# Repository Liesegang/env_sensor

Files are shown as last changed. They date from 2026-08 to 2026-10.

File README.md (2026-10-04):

# Environment sensors

機種ごとに回路・ファームウェア・受信アプリ・プロトコルをまとめる。

```text
card/
  hardware/       KiCad / Fusionの回路・基板・3Dモデル
  firmware/       実装用ディレクトリ
outdoor/
  hardware/       env_sensor_3の回路・基板
  firmware/       nRF54L15 / Zephyr、driver/に各センサー
  software/       TypeScript / ReactのWeb BLE受信アプリ
  protocol/       BLEの共通スキーマ・Cコード生成
room/
  hardware/       env_sensor_1aの回路・基板
docs/
  datasheets/     機種共通のメーカー資料
```

Outdoorの開発・検証は[ファームウェア](outdoor/firmware/README.md)、
[Web受信アプリ](outdoor/software/README.md)、[BLE仕様](outdoor/protocol/README.md)を参照。
資料の一覧は[データシート](docs/datasheets/README.md)にある。

BMV080のIC9はセンサーpinとコネクターpadの対応が反転している。
[配線の照合結果](outdoor/hardware/BMV080-pin-review.md)を参照。回路・基板の配線は未修正。

リポジトリのルートから実行する：

```sh
python3 outdoor/protocol/generate.py --check
outdoor/firmware/scripts/fw test
cd outdoor/software
npm ci
npm run dev
```

ファームウェアのSDK、バックアップ、実機ログは`outdoor/firmware/.local/`へ保存し、Gitに含めない。

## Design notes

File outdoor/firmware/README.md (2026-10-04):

# Outdoor 基板のファームウェア

`outdoor/hardware/env_sensor_3.fsch` / `.fbrd`用のnRF Connect SDK / Zephyrアプリ。
ディレクトリは`outdoor/firmware`。回路・受信アプリ・プロトコルも`outdoor/`配下に置く。
起動時にブザーを停止し、I2Cを1回スキャンした後、各測定値を1秒ごとに`printk()`する。
ブザー試験は無効。BLEは同じ測定値を1秒ごとにNotifyする。

## 実装型番と接続

回路の`parts/part`の`PARTS`属性とユーザーの指定を優先する。
流用されたパッド、記号、ライブラリの名前から実装型番を決めない。

| 部品 | 型番の根拠 | センサー | 接続 |
| --- | --- | --- | --- |
| IC3 | ユーザーが実装型番を確認 | SFA40 | MCU側I2C `0x5d`、実機検証済み |
| IC4 | 実機device ID=`0x0121` | OPT4001 | MCU側I2C `0x45` |
| IC5 | `PARTS=bme690` | BME690 | MCU側I2C `0x76` |
| IC6 | `PARTS=spg41`（回路の表記） | SGP41 | MCU側I2C `0x59` |
| IC7 | `PARTS=SHT4x-Axx`、ユーザー指定はSHT45 | SHT45 | STCC4の補助I2C |
| IC8 | partsの`value=STCC4-D-R3`、product IDを取得済み | STCC4 | MCU側I2C `0x64` |
| IC9 | partsの`value=BMV080`、ユーザーが型番を確認 | BMV080 | MCU側I2C `0x54`、未接続・配線修正が必要 |
| IC10 | partsの`deviceset=AS3935`を暫定採用、`PARTS`未指定 | AS3935 | MCU側I2C `0x03`は仮設定、未接続 |

TWIM30、SCL=P0.03、SDA=P0.04、100kHzを使う。
R5/R6は5.1kΩの外部プルアップ。PCA9515のENは3.3Vにつながり、
下流のSCL1/SDA1へ接続される。
SHT45はSTCC4の専用SCL_C/SDA_Cにつながるため、STCC4が取得した温湿度を利用する。

スキャンは起動後1秒待ち、7bitアドレス`0x01..0x03`と`0x08..0x77`を
データ長0のWriteとSTOPで調べる。スキャンでは測定コマンドを送らない。
NACKは未検出、タイムアウト等は異常として表示し中断する。
起動時のバス復旧に失敗した場合はSCL/SDAの状態を表示する。

## ドライバーと取得値

すべてのモジュールを`driver/`へ置く。各`include/`が公開API。
通常のAPIは成功時0、失敗時に負のerrnoを返す。初期化失敗はセンサーごとに表示し、
ほかのセンサーの取得を続ける。読み取り失敗時には古い値を表示しない。

| モジュール | 取得・表示する値 |
| --- | --- |
| `opt4001` | 照度lux、mantissa、exponent、counter、device ID |
| `bme690` | 温度°C、湿度%RH、気圧Pa、ガス抵抗Ω、gas valid、heater stable、status、測定index、gas index、heater設定、chip ID、variant ID |
| `sgp41` | VOC Index、NOx Indexと各有効フラグ、raw VOC・NOx、NOx raw有効フラグ、conditioning、補償入力と出所、self-test結果、serial |
| `stcc4` | CO₂ ppm、status、product ID、serial、SHT45のraw温湿度 |
| `sht45` | STCC4経由のraw値を温度°C・湿度%RHへ変換 |
| `bmv080` | PM1.0・PM2.5・PM10の質量濃度と粒子数濃度、遮蔽・範囲外フラグ、経過時間。SDK v11.2.0でビルド確認済み、通常構成は無効 |
| `as3935` | 雷・過大ノイズ・妨害信号のイベント、エネルギー、推定距離・頭上・範囲外、検出設定、RC校正状態。現在は無効 |
| `sfa40` | HCHO ppb、温度°C、湿度%RH、raw値、暖機状態、product ID、serial。通常構成で有効 |
| `buzzer` | `buzzer_init()`、`buzzer_start()`、`buzzer_stop()`によるPWM制御 |
| `common` | SensirionのCRC8・I2Cコマンド、SGP41補償値、OPT4001のデコード |

各周期は`SAMPLE <連番> at <経過ms> ms`から始まる。
変換待ち時間を含めて開始時刻を1秒間隔に保ち、周期を超えた場合は
期限を過ぎた分をスキップして`SAMPLE OVERRUN`を表示する。
温度・湿度は内部ではm°C・0.001%RHとして保持し、整数で小数表示する。

SGP41は最初の10秒間をconditioningとし、その間は`raw_nox=0 nox_valid=0`。
その後VOCとNOxの両方を取得する。補償には同じ周期のSHT45温湿度を優先し、
取得失敗時はBME690、両方失敗時は25°C・50%RHを使う。
Sensirion公式Gas Index Algorithm v3.2.0でVOC Index・NOx Index（1〜500）へ変換する。
最初の約45秒はアルゴリズムの暖機中として有効フラグをfalseにし、Webでは`—`を表示する。
NOxはconditioning後から暖機を始める。欠測時は履歴をリセットする。
raw値は詳細表示・CSV用に保持する。[SGP41の変換と検証](driver/sgp41/README.md)を参照。

STCC4の測定周期は内部クロックの許容差により1000ms ±150ms。
データ未準備のNACK時はコマンドを再送せず、150ms後に1回だけ再読する。
再読でも未準備なら`-EAGAIN`として欠測を通知し、以前の値は再利用しない。

BME690はBosch公式SensorAPI v1.1.0を`driver/bme690/vendor/`に同梱し、
校正データから温湿度・気圧・ガス抵抗を計算する。forced mode、heater 300°C / 100ms。
BSECによるIAQ等は未実装。OPT4001はDTS品の係数437.5µlux/countで変換する。

## 後で接続するセンサー

SFA40は接続を確認し初期設定で有効。BMV080・AS3935は初期設定で無効。無効なモジュールの初期化・読み取りは呼ばない。
接続後、`prj.conf`で必要なものだけ有効にし、ビルド・書き込みする。

```ini
CONFIG_APP_AS3935=y
CONFIG_APP_SFA40=y
```

AS3935のアドレスは`0x03`を仮設定している。実際のモジュールのA0/A1に合わせ、
Devicetreeの`reg`を`0x01`・`0x02`・`0x03`のいずれかへ変更する。
現在の回路にはIRQ接続がないため1秒ごとにポーリングし、周期内の複数イベントは
個別に取得できない。新しい雷かどうかは`lightning`で判定する。
[AS3935の設定とAPI](driver/as3935/README.md)を参照。

SFA40は電源投入後の最初の1分に`ready=0`、最初の10分に`within_spec=0`を表示する。
HCHO濃度と合わせて暖機状態を確認する。[SFA40の設定とAPI](driver/sfa40/README.md)を参照。

ユーザー提供のBMV080 SDK v11.2.0を`.local/`へ導入し、
Cortex-M33のsoft-floatライブラリでARMビルドとリンクを確認した。
実機のPM測定は未検証。基板IC9のpin/pad対応は反転しているため、
[配線の照合結果](../hardware/BMV080-pin-review.md)を確認し、接続を修正してから使用する。
コードだけを検証するコマンド（書き込みはしない）：

```sh
./scripts/fw test-bmv080 ~/Downloads/bmv080-sdk-v11-2-0.zip
```
[BMV080の導入手順](driver/bmv080/README.md)を参照。

## 環境と検証

macOSのnRF Connect SDK **v3.4.1**と対応ツールチェーンを使用する。
SDKの標準パスは`/opt/nordic/ncs/v3.4.1`。別の場所では`NCS_DIR`で指定する。
`nrfutil`の`sdk-manager` / `device`とSEGGER J-Linkが必要。

以下は`outdoor/firmware`で実行する。

```sh
nrfutil install sdk-manager
nrfutil install device
./scripts/fw setup
./scripts/fw doctor
./scripts/fw build
./scripts/fw test
```

`test`はビルド後に回路図・PCB・Devicetreeの接続、PARTS指定、PWM極性、
I2Cポート、クロック、DC/DC、RTT、ARM成果物、BLE設定と追加モジュールの有効・無効を11件で検証する。
さらに実際のCコードをホストでコンパイルし、CRC正常値・全1bit破損、
照度・温湿度の単位と境界、SGP41補償を9件で確認する。
追加したAS3935・SFA40の実際のCソースを模擬I2Cで実行し、初期化・CRC・状態・
単位変換・距離コード・IRQ解除・校正・未接続時のエラーを11件で確認する。
STCC4の正常読出し・NACK再読・再読上限・コマンド失敗・CRC破損・タイムアウトを6件で確認する。合計37件。
さらにBLEのCエンコーダーの容量境界・分割を検証し、Webの互換テスト用データを生成する。
通常構成のBMV080は無効側だけがビルド対象。
Gas Indexのconditioning・暖機・基準値・信号変化・欠測・無効入力を実際の公式Cコードで追加検証する。
BMV080のSDK有効側は`test-bmv080`で別途ビルド・11件の構成検証を行う。
成果物は`build/zephyr/zephyr.{elf,hex,bin}`。
センサーAPIには変換待ち時間があるため、割り込みハンドラーから呼ばない。

## 書き込みとリアルタイムログ

CON1は1=nRESET、2=3.3V/VTref、3=SWDIO、4=GND、5=SWCLK。
基板を給電してJ-Linkを接続する。確認したシリアル番号は`69730357`。

```sh
./scripts/fw flash 69730357
```

テスト成功後、既存アプリ領域を`.local/before_flash_*.hex`へ保存し、書き込み・検証・リセットする。
バックアップ失敗時は書き込みを中止する。recoverや全消去は自動実行しない。

デバイスの`printk()` / `printf()`はSWD経由のSEGGER RTT channel 0へ出力する。
ターミナル1で受信を開始する：

```sh
cd /Users/yuki/src/github.com/Liesegang/env_sensor/outdoor/firmware
./scripts/fw rtt 69730357
```

ターミナル2でリアルタイムに表示する：

```sh
tail -F /Users/yuki/src/github.com/Liesegang/env_sensor/outdoor/firmware/.local/rtt.log
```

`rtt`はELFからRTTのアドレスを取得する。既存の`rtt.log`は
`rtt_previous_<日時>_<pid>.log`に退避する。終了は任意のキーまたはCtrl+C。
電源を入れ直した場合はLoggerも起動し直す。RTTは8KiBのノンブロッキング設定で、
受信していない間はログが欠落することがある。

## BLEとWeb受信

`CONFIG_APP_BLE=y`で`Outdoor Sensor`として接続可能な広告を出す。
Service UUIDは`722acd80-e77f-468d-a916-67e599e7cffd`。
Read / Notifyの測定characteristicは`722acd81-e77f-468d-a916-67e599e7cffd`の1つ。
1秒の取得が完了するたびに、全ドライバーの値・状態・errnoを1パケットにまとめて通知する。
MTUが小さい場合は同じcharacteristicで分割する。
送信は専用スレッドで実行し、I2C取得周期を維持する。切断後は広告を再開する。

BLEのため内部RCの校正とPSA乱数源を有効にする。LFXOは無効、ブザーは停止したまま。
HFXOの内部負荷容量15pFはNordic DKの設定を参照した実機動作確認済みの設定であり、
KAGA FEIのモジュール仕様から得た推奨値ではない。
受信画面は[outdoor/software](../software/README.md)、
バイナリの定義は[protocol/outdoor-v1.json](../protocol/outdoor-v1.json)と
[プロトコル仕様](../protocol/README.md)を参照。

## ブザーとMCU

MCUはKAGA FEI ES4L15BA1 / nRF54L15、対象は`env_sensor_outdoor/nrf54l15/cpuapp`。
PWM20 channel 0 → P1.01 → R1 180Ω → TR1 2SC3265 → BUZZ1 UGCT7525。
Highで駆動し、停止時はLow。通常は初期化と停止だけを行う。
P1.01と兼用のLFXOを無効にし、内部RCとGRTCのsystem LFCLK（校正する内部RC）を使う。
モジュール仕様に合わせてL1を使うDC/DCモードを指定する。UARTコンソールは無効。

設定は`prj.conf`。`CONFIG_APP_BUZZER_TEST=n`で無音を維持する。
テストを有効にすると2秒待ち、2kHz・duty 50%で1秒間隔に3回、各50ms鳴らす。
`CONFIG_BUZZER_DUTY_PERMILLE`は500が50%、100が10%、10が1%。

## 実機の状況（2026-10-04）

- SDK v3.4.1 / Zephyr v4.4.2 / GCC 14.3.0で、移動後の通常構成のARMビルド・37件のテスト、Gas IndexとCエンコーダーの検証に成功。
- BMV080 SDK・AS3935・SFA40を同時に有効にした全7センサー構成もARMビルド・11件の構成検証に成功。RAMは162432 bytes。追加ドライバーは実機未検証。
- nRF54L15 REV2の書き込み・検証・リセットと、ブザー停止を確認。
- I2C `0x45`・`0x59`・`0x64`・`0x76`を検出済み。
- OPT4001の照度、STCC4のCO₂・SHT45温湿度と識別情報を取得済み。
- BMV080接続時は`I2C bus recovery: -140; SCL=1 SDA=0`。電源の入れ直しでも解消せず、BMV080を外すと復旧した。BMV080側の接続は確認が必要。
- BMV080を外した状態で、OPT4001・BME690・STCC4/SHT45・SGP41の38周期すべてを1000ms間隔で取得し、エラー・周期超過なしを確認。
- SGP41は最初の10周期がconditioning、以降はVOC・NOx両方が有効。BME690はgas valid / heater stableを確認。
- BMV080 SDK v11.2.0有効側のARMビルド・リンクと11件の構成検証に成功。PM値は実機未取得。
- `Outdoor Sensor`へスマホのBLEデバッグアプリから接続できたことをユーザーが確認。
- SFA40追加前の通常構成をJ-Link `69730357`へバックアップ後に書き込み・検証・リセット済み。BMV080・AS3935・SFA40は無効、ブザーは停止。
- STCC4の150ms再読処理追加後、126周期（sample 22〜147）を1000ms間隔で記録。周期超過なし。VOCは48回目、NOxは57回目からIndexが有効になった。
- sample 28でOPT4001のチェックサムエラー`-77`が1回あり、不正値を破棄して次周期で復帰。sample 113でSTCC4が再読後も未準備の`-11`を返し、その周期はBME690の温湿度でSGP41を補償。次周期でSTCC4/SHT45へ復帰した。
- MacのCoreBluetoothでService・Read/Notify characteristicを確認。実際のReadと連続15回のNotifyをWebの`src/protocol.ts`でデコードし、連番・1000ms周期・有効なVOC/NOx Index・SHT45補償入力の一致を検証。切断後の広告再開も確認。
- ブラウザーから実機へのWeb Bluetooth接続・画面描画は未検証。追加3センサーとPM値は未検証。

検証ログは`.local/sensor_verified.log`。例：照度65.944lux、BME690温度23.120°C、
湿度54.880%RH、気圧101803Pa、ガス抵抗8100Ω、CO₂ 391ppm、
SHT45温度23.274°C・湿度54.908%RH、SGP41 raw VOC=29429・raw NOx=17492。

今回の実機ログは`.local/sensor_verified_20261004_connected.log`、
検証結果は`.local/connected_sensor_validation.json`と`.local/ble_verified_after_retry_validation.json`。
BLE sample 101ではSHT45温度23.456°C・湿度58.845%RH、CO₂ 413ppm、
照度40.340lux、VOC Index 89・NOx Index 1を受信した。

バックアップ、実機ログ、SDKはGit対象外の`.local/`へ保存する。
データシートは共通の[docs/datasheets](../../docs/datasheets/README.md)へ集約する。

## 参照

- [TI OPT4001](https://www.ti.com/lit/ds/symlink/opt4001.pdf)
- [Sensirion SGP41](https://github.com/Sensirion/embedded-i2c-sgp41)
- [Sensirion STCC4](https://github.com/Sensirion/embedded-i2c-stcc4)
- [Sensirion SHT4x](https://sensirion.com/resource/datasheet/sht4x)
- [Bosch BME690 SensorAPI](https://github.com/boschsensortec/BME690_SensorAPI/tree/8a4d9229aaa26c960ca8f7717cb93087f067ecbe)
- [Bosch BMV080 SDK](https://www.bosch-sensortec.com/en/software-tools/double-opt-in-forms/sdk-v11-2.html)
- [AS3935データシート](https://www.sciosense.com/wp-content/uploads/2024/01/AS3935-Datasheet.pdf)
- [Sensirion SFA40公式ドライバー](https://github.com/Sensirion/embedded-i2c-sfa4x/tree/1d7da43d9bd88ad5d9636d18807f52dbb6b86b4a)
- [SEGGER RTT Logger](https://kb.segger.com/J-Link_RTT_Logger)
- [MCU仕様](../../docs/datasheets/ES4L15BA1_DataSheet_V1_0_20260624E.pdf)

## SFA40追加後の実機確認（2026-10-04）

`CONFIG_APP_SFA40=y`で通常構成をビルド・全チェック後、J-Link `69730357`へ
既存アプリをバックアップして書き込み・検証・リセットした。ブザーは停止。
I2Cは`0x45 / 0x59 / 0x5d / 0x64 / 0x76`の5デバイスを検出。
SFA40のproduct ID `0x09020283`、serial `4f926e9f20dc`を確認し、
暖機の最初の1分後に`ready=1`となりHCHO 2.5ppbを取得した。
10分の安定化完了は今回の確認範囲外。
MacのCoreBluetoothでReadと15回のNotify（sequence 49〜63、1秒間隔）を受信し、
Webアプリの`src/protocol.ts`でデコードを検証した。有効マスクは`0x4f`。
検証ログは`.local/sfa40_flash.log`、`.local/sfa40_verified_rtt.log`、
`.local/ble_sfa40.jsonl`、`.local/ble_sfa40_validation.json`。

## SD CSVとブラウザー時刻同期

通常構成で`CONFIG_APP_SD_LOG=y`。毎秒の取得結果をRAMへ保存し、別スレッドが
約1分ごとにSDカードの`OUTDOOR/00000001.CSV`等へまとめて書き込み・同期する。
既存のFATカードを使用し、自動フォーマットは無効。全センサーの値と状態を残す。
時刻は同じBLE characteristicへのWriteでブラウザーから受け取り、
system LFCLK（校正する内部RC）を使うGRTCの稼働時間で維持する。
電源断・リセット後は再同期する。未同期の行は日時を空欄にして稼働時間を残す。
[形式・設定・エラー時の動作](logging/README.md)を参照。

2026-10-04に基板へFAT32カードを挿し、60件単位の保存成功を確認した。
PCに挿し替えた実カードのCSV（240行・95列）を読み取り、日時・状態・単位を検証済み。
14サンプル・1148フィールドを実BLEデータと照合し、すべて一致した。
SD未挿入中のバッファ超過による173サンプルの欠測も検出した。
詳細と検証コマンドは[SD記録の実機確認](logging/README.md)を参照。

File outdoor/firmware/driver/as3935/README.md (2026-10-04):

# AS3935 雷センサー

回路のIC10のparts定義にある`deviceset=AS3935`を暫定採用したドライバー。
`PARTS`属性による型番の指定はないため、接続時に実際のモジュールを確認する。
現在は未接続。`CONFIG_APP_AS3935=n`では初期化・読み取りを呼ばない。

## 有効化と接続

`prj.conf`で`CONFIG_APP_AS3935=y`にすると、既存の1秒周期で状態を`printk()`する。
TWIM30へPCA9515のSCL1/SDA1を介して接続する。
回路にはアドレス設定の配線がないため、Devicetreeの`lightning@3` / `reg = <0x03>`は仮設定。
モジュールのA0/A1に合わせて、使用可能な`0x01`・`0x02`・`0x03`から選ぶ。

現在の回路にはMCUへのIRQ接続がないため、1秒ごとにイベントレジスターをポーリングする。
レジスター0x03の読み取りでIRQが解除される。周期内の複数イベントは個別に取得できない。
IRQを接続する場合は、立ち上がり後にスレッドから`as3935_read()`を呼ぶ。
API内で読み取り前に2ms待つため、割り込みハンドラーから直接呼ばない。

## APIと取得値

- `as3935_init()`：屋外用ゲイン・検出条件を設定し、TRCO/SRCOを校正。校正失敗はエラーを返す。
- `as3935_read()`：割り込み理由、雷・過大ノイズ・妨害信号フラグ、21bitのエネルギー値、距離コード、設定値、校正状態を取得。
- `as3935_calibrate()`：RC発振器を再校正。
- `as3935_clear_statistics()`：距離推定用の雷統計をクリア。
- `as3935_stop()`：パワーダウン。

エネルギー値はセンサー固有の数値で、ジュールへの変換はしない。
新しい雷の検出は`lightning`で判定する。エネルギー・距離は以前のイベントの値を保持する場合がある。
`distance_km`は数値の推定がある場合だけkmを返し、それ以外は`-1`。
頭上は`storm_overhead`、範囲外は`out_of_range`で区別し、`distance_code`も保持する。

Devicetreeで`indoor`、`noise-floor-level`、`watchdog-threshold`、`spike-rejection`、
`minimum-lightnings`、`mask-disturbers`を変更できる。
`tuning-capacitor`を指定しない場合は既存のアンテナ調整値を保持する。
指定する場合は0〜15、1段階8pF。アンテナの共振調整は接続後に確認する。

## 検証と参照

実際のCソースを模擬I2Cで実行し、設定値・予約ビットの保持、校正失敗、
割り込みの解除、エネルギー・距離コード、統計クリアをテスト済み。
有効構成のARMビルドは確認済み。実機での通信・雷検出は未検証。

- [メーカーのAS3935データシート](https://www.sciosense.com/wp-content/uploads/2024/01/AS3935-Datasheet.pdf) v1-04、レジスター定義・Interrupt Management・RC Oscillators

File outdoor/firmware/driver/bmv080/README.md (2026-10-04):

# BMV080 SDK 接続モジュール

実装型番はユーザーがBMV080と確認済み。回路のIC9の`value`も`BMV080`。
PS=High、CSB/A1=Low、MISO/A0=LowのI2Cアドレス`0x54`を使用する。
SCL1/SDA1からPCA9515を介してTWIM30へ接続する設計だが、現在の基板の
pin/pad対応は逆になっている。[IC9の配線照合](../../../hardware/BMV080-pin-review.md)を参照。

ユーザー提供のBosch公式SDK v11.2.0を導入し、Cortex-M33のARMビルドとリンクを確認済み。
通常ビルドでは`CONFIG_APP_BMV080=n`で、
アプリは初期化・読み取りを呼ばない。無効側の`bmv080_driver_init()`は`-ENOSYS`を返す。
実機のPM測定は未検証。デバイス切断中のため今回のコードは書き込んでいない。

## SDKの導入

`outdoor/firmware`で実行する。ユーザー提供のZIPから必要なファイルを
Git対象外の`.local/bmv080-sdk-v11-2-0/`へ展開する。
現在の`CONFIG_FPU=n`に合わせ、ARM GCC / Cortex-M33のsoft-float版を使う。
SDKはリポジトリに同梱しない。

```sh
./scripts/fw test-bmv080 ~/Downloads/bmv080-sdk-v11-2-0.zip
```

`.local/bmv080_sdk.conf`を生成し、`.local/build_bmv080`へビルドする。
ZIPのSHA-256を`IMPORT.txt`へ記録する。通常構成の`prj.conf`は変更せず、書き込みもしない。
次回からは`./scripts/fw test-bmv080`だけで検証できる。

生成する追加設定は次の内容。配置を移動した場合は上のZIP指定コマンドを再実行する。

```ini
CONFIG_APP_BMV080=y
CONFIG_MAIN_STACK_SIZE=16384
CONFIG_COMMON_LIBC_MALLOC_ARENA_SIZE=65536
CONFIG_BMV080_SDK_INCLUDE_DIR="/absolute/path/to/directory/containing/bmv080.h"
CONFIG_BMV080_SDK_DRIVER_LIBRARY="/absolute/path/to/arm-cortex-m33/lib_bmv080.a"
CONFIG_BMV080_SDK_POSTPROCESSOR_LIBRARY="/absolute/path/to/arm-cortex-m33/lib_postProcessor.a"
```

SDK v11.2.0有効構成のビルド・リンクと11件の基板構成検証が通過した。
Flashは240876 bytes、RAMは162408 bytes（256KiBの約62%）を使用する。
検証ログは`.local/reorganized_bmv080_test.log`。
コードの検証は実機の通信・PM値・動作時のスタック使用量を保証するものではない。
SDKファイル不足、またはmainスタックが12KiB未満の場合はCMakeで停止する。
SDKの仕様では10KiBのスタックが必要。

## 取得内容とスケジュール

- PM1.0・PM2.5・PM10の質量濃度（µg/m³）と粒子数濃度（particles/cm³）
- 遮蔽フラグ、測定範囲外フラグ、測定開始後の経過時間
- 受信連番、受信からの経過時間、前回printkから更新されたかの`fresh`フラグ

連続測定開始後、16KiBスタックの専用スレッドでSDKを10msごとにサービスする。
mainは1秒ごとに最新の結果を取り出す。最大出力レートは約0.97Hzなので、
更新がない回は`fresh=0`と`age_ms`で区別する。最初の結果までは`-EAGAIN`。
SDKの予約フィールドと内部専用ポインタは公開しない。

SDK初期化時にI2Cを400kHzへ切り替える。16bitヘッダーとデータをMSB-firstで転送し、
readはヘッダー送信後にSTOPを入れる。readは128wordごとに分割し、
writeは最大2048wordまで。実機での転送は未検証。

## 参照

- [保存したBosch BMV080データシート](../../../../docs/datasheets/Bosch_BMV080_datasheet.pdf) §4.4.2、§5
- [対応プラットフォーム](https://www.bosch-sensortec.com/media/boschsensortec/software_tools/software/bmv080_1/supported_platforms/bmv080_binary_size_information.pdf)
- [Bosch公式のSDK統合例](https://github.com/boschsensortec/BMV_BME/tree/a94b769/src)

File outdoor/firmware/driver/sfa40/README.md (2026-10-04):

# SFA40 ホルムアルデヒドセンサー

ユーザーが実装型番をSFA40と確認したIC3のドライバー。
2026-10-04に接続を確認し、初期設定は`CONFIG_APP_SFA40=y`。
`CONFIG_APP_SFA40=n`では初期化・読み取りを呼ばない。
SFA40のコマンドとCRCを使用する。

## 有効化と接続

SCL1/SDA1からPCA9515を介してTWIM30へ接続する。I2Cアドレスは`0x5d`。
`prj.conf`で`CONFIG_APP_SFA40=y`にすると、既存の1秒周期で値を`printk()`する。

## APIと取得値

- `sfa40_init()`：測定停止、product ID・serial取得、連続測定開始。
- `sfa40_read()`：HCHO濃度、温度、相対湿度、raw値、状態、識別情報を取得。
- `sfa40_stop()`：連続測定を停止。

HCHOは`hcho_millippb`（0.001ppb単位、センサー分解能は0.1ppb）、
温度は`temperature_mc`（0.001°C）、湿度は`humidity_mpercent`（0.001%RH）。
受信データの各ワードのCRCを検証し、異常時は負のerrnoを返して出力構造体を更新しない。
測定開始から最初の500msは`-EAGAIN`。APIは待ち時間を含むためスレッドから呼ぶ。

暖機状態は受信したstatusの上位バイトから取得する。
電源投入後の最初の1分は`ready=0`、HCHO出力は0。
1〜10分は`ready=1 within_specification=0`、10分以降は両方1。
温湿度と濃度を表示するときも、この状態フラグを併記する。

## 検証と参照

実際のCソースを模擬I2Cで実行し、コマンド・識別情報・初回待ち、
CRC異常、statusの位置と暖機フラグ、単位変換と境界値、未接続時のエラーをテスト済み。
有効構成のARMビルド・実機書き込みを確認済み。2026-10-04の実機で`0x5d`を検出し、
product ID `0x09020283`、serial `4f926e9f20dc`を取得した。
1秒周期の読み取りと、最初の1分の`ready=0`から`ready=1`への遷移を確認。
BLE Readと15回のNotifyもWebアプリと同じデコーダーで検証し、
HCHO 2.5ppb・温度26.631°C・湿度49.996%RHを取得した。
この時点では`within_specification=0`で、10分の安定化完了は未確認。

- [Sensirion SFA40データシート](https://sensirion.com/media/documents/5B06EDD9/69F84BD8/Sensirion_Datasheet_SFA40.pdf) Version 1.1、April 2026
- [Sensirion公式組み込みドライバー](https://github.com/Sensirion/embedded-i2c-sfa4x/tree/1d7da43d9bd88ad5d9636d18807f52dbb6b86b4a)：コマンド・停止後700msの待ち時間を参照

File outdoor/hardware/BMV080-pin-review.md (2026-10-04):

# BMV080 / IC9のpinとpadの照合

2026-10-04に`env_sensor_3.fsch`と`env_sensor_3.fbrd`のXMLを照合した。
型番はユーザーが確認したBMV080を採用する。回路のIC9の`value`もBMV080。
ライブラリや記号名から型番を推定していない。

**現在の対応は反転している。回路・基板の配線はこの調査では変更していない。**

## 向きと番号

IC9のpackageは`CON_5035661302_MOL`。実際のpad座標では、
奇数padがy=-1.12、偶数padがy=+1.31にあり、番号は左から右へ増える。
MolexのBottom ContactコネクターではFPCを奇数pad側から挿入する。
基板のセンサー外形もこの方向（packageのyが負の側）へ延び、
光学窓の位置もBoschのTop Viewを180度回転した向きに一致する。

BoschのTop Viewは、センサー本体が上・接点が下のとき、pin 1が左、pin 13が右。
コネクターへ挿入する向きに180度回すとpin 1が右になり、
基板pad 13へ接触する。したがって、**BMV080 pin = 14 - 基板pad**。
PCB上のIC9の配置角度R90はこの相対的な対応を変えない。

Molexの断面図では、挿入口側に出ている奇数端子の内部接点は奥側にあり、
奥側に出ている偶数端子の内部接点は手前側にある。
外側のはんだ端子の前後位置と、FPCへ接触する位置は入れ替わるが、
各端子の左右位置と電気的な番号は変わらない。

現在のライブラリ`connects`はpin 1→pad 1、pin 2→pad 2という同番号の対応になっている。
回路図とPCBのネットは一致するが、物理的な接点の対応とは一致しない。

## 正しいネット割り当て

PS=HighのI2C、アドレス`0x54`（IAB1=Low、IAB0=Low）を使う場合：

| 基板pad | BMV080 pin | 実際の機能 | 現在のネット | 必要なネット |
| --- | --- | --- | --- | --- |
| 1 | 13 | DNC / 内部試験用 | +3V3 | 未接続 |
| 2 | 12 | IRQ | GND | 未接続（現在はポーリング） |
| 3 | 11 | IAB0 | +3V3 | GND |
| 4 | 10 | VDDD | GND | +3V3 |
| 5 | 9 | VSSD | SDA1 | GND |
| 6 | 8 | VDDIO | SCL1 | +3V3 |
| 7 | 7 | PS | +3V3 | +3V3 |
| 8 | 6 | SCL | +3V3 | SCL1 |
| 9 | 5 | SDA | GND | SDA1 |
| 10 | 4 | IAB1 | +3V3 | GND |
| 11 | 3 | VDDA | GND | +3V3 |
| 12 | 2 | VSSA | 未接続 | GND |
| 13 | 1 | VDDL | 未接続 | +3V3 |

電源padは13・11・6・4、GND padは12・5、SCLは8、SDAは9。
pad 7はI2C選択のHigh、pad 10・3はアドレス選択のLow。
13番センサーpinはメーカー指定で電源・GNDを接続しない。

現在のSDA1はセンサーのVSSDへ接続され、センサーSDAは基板GNDへ接続される。
過去にBMV080を接続するとSDA=Low、外すとバスが復旧した症状と整合する。
これは図面からの照合結果であり、接点の導通は実機では確認していない。

## 推奨コネクターの比較

BoschのPDF p.16はMolex 503566-1302、KYOCERA AVX 046844713002846+、
Greenconn CFTD104-1302A001C2ADを適合コネクターとして挙げている。
同ページの注記は、BMV080とZIFコネクターではpin番号の付け方が異なり得ると明記する。

MolexのPDF p.3と京セラのBJS6844006 PDF p.1を比較すると、両者とも下接点で、
外側のはんだ端子は挿入口側に7本、奥側に6本の配置になっている。
少なくともこの2種類で外側端子の前後配置が異なる、という根拠はない。
適合FPCの記載だけから、基板フットプリントやpin番号の互換性は判断しない。
Greenconnの該当型番のメーカー図面は未取得のため、配置・番号は未確認。
どの資料の取り違えによって現在のCADが作られたかは、この照合からは特定できない。

## 参照資料

- [Bosch BMV080 datasheet](../../docs/datasheets/Bosch_BMV080_datasheet.pdf)、BST-BMV080-DS000-12：p.17 Figure 11（番号の相違）、p.26 Figure 24（Top/Bottom View）、p.27 Table 11（pin機能）、p.28 Figure 26（3.3V接続例）。
- [Molex 5035661302 drawing](../../docs/datasheets/Molex_5035661302_drawing.pdf)、5035661001 PSD 000 Rev A：PDF p.3断面図（Bottom Contactと挿入方向）、p.4推奨PCBパターン。
- [KYOCERA AVX 046844713002846+ drawing](../../docs/datasheets/Kyocera_046844713002846_drawing.pdf)、BJS6844006 Rev J：PDF p.1（13極の外形・基板パターン）、p.3（適合FPC）。
- [Bosch公式配布元](https://www.bosch-sensortec.com/media/boschsensortec/downloads/datasheets/bst-bmv080-ds000.pdf)。
- [Molex公式配布元](https://www.molex.com/content/dam/molex/molex-dot-com/products/automated/en-us/salesdrawingpdf/503/503566/5035661302_sd.pdf)。

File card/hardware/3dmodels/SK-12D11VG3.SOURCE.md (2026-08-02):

# SK-12D11VG3 3D model

- File: `SK-12D11VG3.step`
- Source: <https://github.com/issaimaru/TakenTracker/blob/984b7f219c4a60cfc3c2723267b09084e8f2efa2/Freecadlib/SK-12D11VG3.step>
- Source commit: `984b7f219c4a60cfc3c2723267b09084e8f2efa2`
- Retrieved: 2026-08-03
- License: Apache License 2.0 (see `LICENSE.Apache-2.0.txt`)
- SHA-256: `789CFF4E13C7D524F5CCFBA8E0500B0FFAD1C28B93CE12129790246B600D0DCC`
- Modification: none

The model was rendered with KiCad 10 and visually compared with the Akizuki
product photos and mechanical drawing. Its metal cover, side actuator, three
electrical terminals, and two mounting tabs match the SK-12D11VG3. Use the
manufacturer's mechanical drawing, rather than the 3D model alone, for final
clearance and manufacturing decisions.

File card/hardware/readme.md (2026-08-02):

# card_env_sensor

## I²C アドレス

アドレスは R/W ビットを含まない 7-bit 表記である。

回路図のアドレス選択端子の接続を反映した通信先は次のとおり。

| リファレンス | デバイス | I²C アドレス | アドレスの決定条件 | 資料箇所 |
| --- | --- | ---: | --- | ---: |
| IC3 | [BME690](../docs/BME690_datasheet.pdf) | `0x76` | `SDO = GND`。`SDO = VDDIO` では `0x77` | p. 46 |
| IC4 | [SGP41-D-R4](../docs/Sensirion_Gas_Sensors_Datasheet_SGP41.pdf) | `0x59` | 固定 | p. 12 |
| IC5 | [STCC4-D-R3](../docs/CD_DS_STCC4_D1.pdf) | `0x64` | `ADDR = GND`。`ADDR = VDD` では `0x65` | p. 5 |
| U1 | [SHT45](../docs/HT_DS_Datasheet_SHT4x_5.pdf) | `0x44` | 固定。STCC4 の SHT4x 接続用バスに接続 | p. 1 |
| IC6 | [SFA40](../docs/Sensirion_Datasheet_SFA40.pdf) | `0x5D` | 固定 | p. 7 |
| IC7 | [OPT4001YMNR](../docs/opt4001.pdf) | `0x45` | YMN（PicoStar）パッケージで固定 | p. 21 |
| IC2 | [nPM1300-QEXX](../docs/nPM1300_PS_v1.3.pdf) | `0x6B` | 固定 | p. 125 |

> [!NOTE]
> SHT45（U1）はメインの `SCL` / `SDA` バスではなく、STCC4（IC5）の SHT4x 接続用バス `SCL_C` / `SDA_C` に接続されている。
> ホストは SHT45 をメインバスから直接アドレス指定せず、STCC4 内蔵の I²C コントローラーが SHT45 と通信する。

## ほかの I²C 接続

回路図上で I²C ターゲットとして接続されているデバイスは、上表の7個だけである。

IC1 はホスト側のコントローラーであり、I²C ターゲットには数えない。

e-Paper コネクタ（CON2）の `TSCL` と `TSDA` は未接続である。

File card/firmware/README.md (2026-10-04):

# Card firmware

Card用ファームウェアの配置先。現在のリポジトリには実装はまだない。
回路・基板は[../hardware](../hardware/)を参照。

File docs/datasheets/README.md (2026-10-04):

# データシート・メーカー図面

Card / Outdoor / Roomの共通資料をここへ集約する。PDFは原本のまま保存する。
元の`hardware/docs/`にあった15件と、BMV080・AS3935・Molex・京セラ・SFA40取扱資料の5件、計20件。
各PDFを開けることとページ数を確認した。

| 型番・資料 | 保存ファイル | ページ数 |
| --- | --- | --- |
| Bosch Sensortec / BMV080 | [Bosch_BMV080_datasheet.pdf](Bosch_BMV080_datasheet.pdf) | 53 |
| Molex / 5035661302 | [Molex_5035661302_drawing.pdf](Molex_5035661302_drawing.pdf) | 4 |
| KYOCERA AVX / 046844713002846+ | [Kyocera_046844713002846_drawing.pdf](Kyocera_046844713002846_drawing.pdf) | 4 |
| ScioSense / AS3935 | [AS3935_datasheet.pdf](AS3935_datasheet.pdf) | 44 |
| Texas Instruments / OPT4001 | [opt4001.pdf](opt4001.pdf) | 56 |
| Bosch Sensortec / BME690 | [BME690_datasheet.pdf](BME690_datasheet.pdf) | 60 |
| Sensirion / STCC4 | [CD_DS_STCC4_D1.pdf](CD_DS_STCC4_D1.pdf) | 18 |
| Sensirion / SHT4x・SHT45 | [HT_DS_Datasheet_SHT4x_5.pdf](HT_DS_Datasheet_SHT4x_5.pdf) | 24 |
| Sensirion / SGP41 | [Sensirion_Gas_Sensors_Datasheet_SGP41.pdf](Sensirion_Gas_Sensors_Datasheet_SGP41.pdf) | 22 |
| Sensirion / SFA40 | [Sensirion_Datasheet_SFA40.pdf](Sensirion_Datasheet_SFA40.pdf) | 19 |
| Sensirion / SFA40取扱・実装 | [Sensirion_Handling_Instructions_SFA40.pdf](Sensirion_Handling_Instructions_SFA40.pdf) | 6 |
| KAGA FEI / ES4L15BA1 | [ES4L15BA1_DataSheet_V1_0_20260624E.pdf](ES4L15BA1_DataSheet_V1_0_20260624E.pdf) | 38 |
| Nordic / nRF54L15・nRF54L10・nRF54L05 | [nRF54L15_nRF54L10_nRF54L05_Datasheet_v1.0.pdf](nRF54L15_nRF54L10_nRF54L05_Datasheet_v1.0.pdf) | 940 |
| Nordic / nPM1300 | [nPM1300_PS_v1.3.pdf](nPM1300_PS_v1.3.pdf) | 175 |
| Same Sky / UJC-HP-3-SMT-TR | [ujc-hp-3-smt-tr.pdf](ujc-hp-3-smt-tr.pdf) | 4 |
| USB Type-C電源接続図 | [ujc-hp-3-smt-tr_powered_by_type-c.pdf](ujc-hp-3-smt-tr_powered_by_type-c.pdf) | 1 |
| Waveshare / 3.6inch e-Paper HAT+ | [3.6inch_e-Paper_HAT+.pdf](3.6inch_e-Paper_HAT+.pdf) | 10 |
| Waveshare / 3.6inch e-Paper HAT+回路図 | [3.6inch_e-Paper_HAT+_Schematic.pdf](3.6inch_e-Paper_HAT+_Schematic.pdf) | 2 |
| スライドスイッチ / SK-22H09G5 | [AKIZUKI-SK-22H09G5.pdf](AKIZUKI-SK-22H09G5.pdf) | 5 |
| トグルスイッチ / TMHU27 | [TMHU27.pdf](TMHU27.pdf) | 2 |

保存時のSHA-256、サイズ、ページ数、由来は[manifest.json](manifest.json)に記録した。
元のリポジトリに取得URLの記録がない資料は、推測したURLを追加していない。
版番号は保存ファイルの内容を参照する。メーカーが後から公開した版への自動更新は行わない。

## 今回の照合に使った資料

- BMV080：Bosch公式[BST-BMV080-DS000](https://www.bosch-sensortec.com/media/boschsensortec/downloads/datasheets/bst-bmv080-ds000.pdf)。保存版はRev 12。
- AS3935：ScioSense公式[AS3935 Datasheet](https://www.sciosense.com/wp-content/uploads/2024/01/AS3935-Datasheet.pdf)。
- Molex：公式[5035661302図面](https://www.molex.com/content/dam/molex/molex-dot-com/products/automated/en-us/salesdrawingpdf/503/503566/5035661302_sd.pdf)。直接取得はタイムアウトしたため、[IC-Componentsに掲載されたメーカー原図](https://www.ic-components.nl/files/de/5035661302.pdf)を保存。図面番号5035661001、Rev A、2017-02-21。
- 京セラ：公式[BJS6844006図面](https://ele.kyocera.com/assets/products/connector/drawing/BJS6844006.pdf)。保存版はRev J、2026-07-01。13極の外形・基板パターンはPDF p.1、適合FPCはp.3。
- SFA40：公式[Handling Instructions](https://sensirion.com/media/documents/57BBCF4B/6A38E93F/Handling-Instructions_SFA40.pdf)。保存版はVersion 1.0、June 2026。上面の保護膜は除去禁止。低温を含むリフロー・熱風はんだは禁止で、他部品のリフロー後に実装する。手はんだはこて先310 °C以下、各端子5秒以内（p.1・4・5）。

BMV080推奨コネクターのうち、Greenconn CFTD104-1302A001C2ADのメーカー図面は未取得。

[BMV080の基板pad照合結果](../../outdoor/hardware/BMV080-pin-review.md)も参照。
Bosch SDKのヘッダー・ライブラリはデータシートと分け、Git対象外の`outdoor/firmware/.local/`に保持する。

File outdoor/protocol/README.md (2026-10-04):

# Outdoor BLE protocol v1

Service: `722acd80-e77f-468d-a916-67e599e7cffd`

測定characteristic: `722acd81-e77f-468d-a916-67e599e7cffd`、Read / Notifyの1つ。
機器名は`Outdoor Sensor`。Service UUIDを広告し、名前をscan responseで送る。
取得完了ごとに1秒周期でNotifyする。Readは同じ最新スナップショットを返す。

## 共通スキーマ

`outdoor-v1.json`がUUID・フィールド順・型・表示単位の共通定義。
すべての整数はlittle-endian。フィールドごとに直列化し、C構造体のパディングを含めない。
`u64`のserialはWeb側で正確な16桁hex文字列、稼働時間はbigintとして保持する。
単位付きの整数はraw値を送信し、Web側で`scale`を適用する。

```sh
python3 outdoor/protocol/generate.py
python3 outdoor/protocol/generate.py --check
```

生成対象は`outdoor/firmware/telemetry/include/telemetry.h`と`telemetry_encode.c`。
Webは同じJSONを直接参照する。ワイヤー互換性が変わる場合はversionを上げる。

## 測定パケット（Readの値）

| Offset | 型 | 内容 |
| --- | --- | --- |
| 0 | 2 byte | ASCII `OE` |
| 2 | u8 | version=1 |
| 3 | u8 | header size=24 |
| 4 | u16 | 全長、最大512byte |
| 6 | u16 | 有効設定のセンサーマスク |
| 8 | u16 | 今周期の読み取り成功マスク |
| 10 | u16 | reserved=0 |
| 12 | u32 | 測定連番、起動直後の準備中パケットは0 |
| 16 | u64 | 読み取り開始時の起動後ms |
| 24〜 | TLV | 有効設定のセンサーごとに1ブロック |

マスクのbitは`id-1`。IDは1=OPT4001、2=BME690、3=SGP41、4=STCC4/SHT45、
5=BMV080、6=AS3935、7=SFA40。初期設定ではSFA40を含む0x4f。

TLVは`id:u8`、`block version:u8`、`body length:u16`、`error:i16`、フィールド列。
SGP41のblock versionは2（VOC/NOx Index追加）、それ以外は1。
旧SGP41 version=1はWeb側でファームウェア更新が必要と表示する。
error=0のときだけJSONに定義した全フィールドを送る。負のerrnoのときbodyはerrorの2byteのみ。
無効設定のセンサーはブロックがない。正常な0と、無効・待機・失敗を区別できる。
SGP41のIndex有効フラグ・NOx raw有効フラグ、SFA40の暖機、BMV080の更新状態等は各ドライバーのフラグも確認する。
VOC/NOxは公式Gas Index Algorithmの計算値（1〜500）を使用し、rawは診断用にも送る。
STCC4ブロックの温湿度フィールドは`source=sht45`とし、WebではSTCC4とSHT45を別表示する。
SGP41の補償元は同じパケットのSTCC4/SHT45→BME690→既定値の成功状態から分かる。
未知のセンサーIDのTLVはWeb側で読み飛ばす。
全7種類が成功したパケットは258byte、通常の4種類では140byte。

## Notifyの分割ヘッダー

通知は常に分割ヘッダーを付ける。1回で収まる場合も同じ形式。

| Offset | 型 | 内容 |
| --- | --- | --- |
| 0 | 2 byte | ASCII `OF` |
| 2 | u8 | version=1 |
| 3 | u8 | reserved=0 |
| 4 | u32 | 元パケットと同じ連番 |
| 8 | u16 | 元パケット全長 |
| 10 | u16 | 元パケット内のpayload開始位置 |
| 12〜 | byte列 | 元パケットの一部 |

転送長はATT MTU-3以下。MTU=23ではpayloadは8byte、MTU=247では232byte。
MTU=247の通常構成は1通知、全7種類は2通知となる。
送信専用スレッドが断片を順番に送る。取得側は待たず、送信待ちの最新値を置き換える。
長いReadの各offsetは最初のRead時点の値に固定し、新しいNotifyと混ざらないようにする。

Webは連番・全長・offsetを確認し、3秒以内に連続受信した完全なパケットだけを採用する。
欠落・順序違い・途中切断は破棄し、次のoffset=0から再開する。
BLE層の再送を超えて通知が欠落した場合、過去の測定を再送する機能はない。

## 検証

`outdoor/firmware/tests/check_telemetry.py`は実際のCエンコーダーをホストでコンパイルし、
容量境界・不正引数・エラーパケット・分割サイズを検証する。
同じCの出力をWebのVitestとPlaywrightが使用し、符号・64bit精度・全センサーの復元・分割・欠落・CSVを確認する。

- [Zephyr GATT API](https://docs.zephyrproject.org/latest/services/connectivity/bluetooth/api/gatt.html)
- [Chrome Web Bluetooth](https://developer.chrome.com/docs/capabilities/bluetooth)

## 時計の同期（Write）

同じcharacteristicはRead / Notifyに加えてWrite With Responseにも対応する。
測定パケットの形式は変えず、Writeだけ別の制御メッセージを受け取る。
ブラウザーはBLE接続時に`Date.now()`を送る。

| Offset | サイズ | 値 |
|---|---:|---|
| 0 | 2 | ASCII `OT` |
| 2 | 1 | バージョン `1` |
| 3 | 1 | 予約 `0` |
| 4 | 8 | UTC Unix milliseconds、unsigned little endian |

全長12 bytes。2020-01-01以上2100-01-01未満を受理する。
ATT Write Responseの成功が同期完了を示す。分割Write・不正な長さ・予約値は拒否する。
GRTCの稼働時間へ日時の基準を対応付け、その起動中は接続がなくても時刻が進む。
再接続では再同期できる。リセット・電源断後は再同期が必要。
CSVの同期前行は時刻を空欄、`clock_synced=0`にして記録する。

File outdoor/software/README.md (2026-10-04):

# Outdoor Web BLE receiver

TypeScript / React / ViteによるBLE受信アプリ。
`Outdoor Sensor`へ接続し、1つのcharacteristicのNotifyから1秒ごとの全センサー値を取得する。
接続直後はReadで最新値も取得する。

## 起動

Node.js 24 LTS以上（開発時は25.9.0）、npmを使用する。

```sh
cd /Users/yuki/src/github.com/Liesegang/env_sensor/outdoor/software
npm ci
npm run dev
```

ChromeまたはEdgeで[http://127.0.0.1:5178](http://127.0.0.1:5178)を開き、
「BLE接続」から`Outdoor Sensor`を選ぶ。ローカル開発以外ではHTTPSを使う。
Web Bluetoothの対応状況・ユーザー操作の要件は[Chrome公式資料](https://developer.chrome.com/docs/capabilities/bluetooth)を参照。

Serviceは`722acd80-e77f-468d-a916-67e599e7cffd`、
characteristicは`722acd81-e77f-468d-a916-67e599e7cffd`。
詳しい形式は[共通プロトコル](../protocol/README.md)。
機器名だけで識別せず、広告中のService UUIDで選択を絞り込む。

## 画面と保存

- 温度・湿度・CO₂・照度・気圧・VOC Index・NOx Indexの最新値。温湿度はSHT45を優先し、失敗時はBME690へ切り替える。
- 全21項目の物理測定値（気圧・照度・各センサーの温湿度・VOC/NOx・CO₂・HCHO・PM質量/粒子数・雷エネルギー/距離）を最新15分、最大900件のグラフに重ねて表示。STCC4とSHT45の所有を分離し、温湿度のセンサー間フォールバックは行わない。
- 単位の違う項目は各項目の表示範囲を0〜100%へ揃え、凡例に最新の実測値・単位・範囲を表示。凡例で個別切り替え、「すべて表示」「すべて非表示」に対応。1項目だけ選ぶと実単位の縦軸を表示。
- 欠測や2.5秒を超える間隔は線をつながない。暖機中のHCHO/Index、無効なガス抵抗・雷イベントの値をグラフに描かない。
- 7つの測定ブロックを8つのセンサーとして表示し、STCC4（CO₂）とSHT45（温湿度）を分離。読み取り失敗は`—`と表示し、無効設定・暖機・失敗を区別する。
- 「詳細を表示」でraw値・識別情報・状態フラグ・UUID・不正通知数を表示。
- CSV保存は保持中の全測定・全rawフィールド・errnoをUTF-8 BOM付きで出力。単位の倍率はJSONスキーマに定義。

VOC/NOxは公式アルゴリズムによるIndex（1〜500）で、ppm/ppbではない。
暖機中のIndexは`—`、SGP41の状態は「暖機中」と表示する。
SGP41 block version=2が必要なため、以前のファームウェアは更新が必要。
2026-10-04に対応ファームウェアを書き込み済み。
MacのCoreBluetoothで実際のRead/Notifyを受信し、`src/protocol.ts`でデコードを確認した。
ブラウザーから実機への接続・描画は引き続き未検証。

データはページのメモリー内に保持する。サーバーへの送信・永続保存は行わない。
再読み込みや新しい接続で履歴が消えるため、必要なデータはCSV保存する。
切断時は最後の測定を残し、「更新停止」を表示する。3.5秒以上受信がない場合も停止として示す。
接続は明示的な操作で開始し、中止・切断時に購読と途中パケットを破棄する。

## コードと検証

`src/protocol.ts`が長さ・バージョン・状態・分割を検証するデコーダー。
`src/bluetooth.ts`が接続と受信を管理し、`useSyncExternalStore`でReactへ状態を渡す。
表示・グラフ・表・CSVは接続管理から分けている。
strict、noUncheckedIndexedAccess、exactOptionalPropertyTypes、React HooksのLintを有効にする。

```sh
npm run build
npm run lint
npm test
npx playwright install chromium --only-shell
npm run test:e2e
```

`npm test`はCエンコーダーをコンパイルするため、Python 3とホストのCコンパイラーが必要。
Nordic SDKや接続した基板は不要。Cの出力からテストベクトルを再生成する。
Playwrightは模擬Web Bluetoothで接続・Notify・分割受信・CSV・中止・再接続・非対応ブラウザーを検証する。
実機による受信とは別のテストである。

画面は組み込みブラウザーでも確認する。Browser専用プラグインは未導入のため、
自動テスト・1536×1024と390×844の確認にはプロジェクトのPlaywrightを使用する。

2026-10-04の移動後の検証はbuild・lint・Vitest 18件・Playwright 8件が通過。
VOC/NOxの暖機中表示、旧SGP41形式の更新案内、STCC4/SHT45分離、
Indexグラフの範囲（1〜500）、1536×1024と390×844の空画面・模擬BLE受信画面を確認した。

## SDログの時計同期

BLE接続時、同じcharacteristicへブラウザーのUTC時刻（`Date.now()`）を
Write With Responseで送る。成功時は受信情報に「時刻同期済み（SDログ用）」を表示する。
書き込み失敗は測定受信を止めず、別の通知で再接続を案内する。
再接続すると同期をやり直す。旧ファームウェアではWriteに非対応なので更新が必要。
デバイスは以後ブラウザー切断中も内部GRTCで時刻を維持し、毎秒の値を1分ごとにSDへ書き込む。
電源断・リセット後は再同期が必要。
[SDログの形式・運用](../firmware/logging/README.md)を参照。

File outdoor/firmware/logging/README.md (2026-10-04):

# SDカードへのCSV記録と時刻同期

毎秒の全センサー取得結果をRAMへ保存し、約60秒ごとに別スレッドでSDへまとめて
書き込み、`fs_sync()`する。平均値に集約せず、各秒の値を1行ずつ残す。
測定・BLEスレッドはSDのマウントや書き込み完了を待たない。

## カードとファイル

- 既存のFAT16/FAT32カードを使う。exFATは無効。自動フォーマットは無効。
- ボードのSPI接続：SCK P1.04（R3経由）、MOSI P1.06、MISO P1.02、CS P2.04。
- P1.02のNFCパッド保護を解除し、GPIO/SPI入力として使用する。
- `spi20`、最大4MHz。ZephyrのSPI SDHC・SDMMC・FatFsを使用する。
- カードの`OUTDOOR/00000001.CSV`から空いている番号へ新しいファイルを作る。
  起動ごとに新規ファイルを選び、既存CSVを上書きしない。
- ヘッダーと全センサーの列は`outdoor/protocol/outdoor-v1.json`から生成する。
  スキーマを変えたら`python3 outdoor/protocol/generate_csv.py`も実行する。

CSVの先頭は`timestamp_utc,clock_synced,sequence,uptime_ms,enabled_mask,valid_mask`。
日時は`2026-10-04T11:40:00.123Z`のようなUTC ISO 8601。
`[°C]`、`[hPa]`、`[ppb]`等の単位付き列は換算済みの値を記録する。
各センサーのerrno・識別情報・raw値・状態フラグも残す。
SHT45の列はSTCC4のパケットから分離して名前を付ける。
無効なセンサーは空欄、失敗時はerrnoを残して測定列を空欄にする。
暖機中の値はセンサー出力とready/validフラグを一緒に保存する。

## 時刻

WebアプリがBLE接続時、既存の測定characteristicへUTC Unix millisecondsを
Write With Responseで送る。書き込みが成功したら「時刻同期済み（SDログ用）」を表示する。
再接続でも同期し直して、その後のサンプルへ反映する。過去のサンプル時刻は変更しない。
GRTCによる64ビット稼働時間と、受け取った日時との差分で時計を維持する。
GRTCはsystem LFCLKを使い、内部RCの校正を有効にしている。
ブラウザーを切断しても、同じ起動中は時計とSD記録が続く。
クロックの誤差とBLE転送遅延があるため、長時間の絶対精度は保証しない。
電源断・リセットでは時刻同期状態が消え、再同期が必要。

同期前のサンプルは日時を空欄にして`clock_synced=0`と稼働時間を保存する。
同期後は`clock_synced=1`。FatFsの更新日時にもUTCを使う。
同期前のファイル更新日時は2020-01-01の仮値となるため、測定日時はCSVの列を参照する。

## エラーと未保存分

書き込みは4KiB単位でまとめ、各分の完了時に同期する。
SD不在・書き込みエラーは10秒後に再試行する。測定は続ける。
3つの分バッファが埋まると、保存できなかった件数をRTTへ`total dropped`として出力する。
エラー時は最後の書き込み前の位置へ切り詰めを試み、失敗したら部分行の可能性をRTTへ出力する。
再試行時は新しいCSVを選ぶ。保存済みファイルの再利用・自動消去はしない。
電源断では未保存のRAM内データが失われる。FATは電源断時の整合性を保証しない。

## 確認

```sh
outdoor/firmware/scripts/fw test
outdoor/firmware/scripts/fw rtt 69730357
```

ブラウザーでBLE接続すると`CLOCK: synchronized from BLE browser time`を出力する。
SDへの保存が成功すると、約1分ごとに`SD LOG: wrote 60 samples ... (synced)`を出力する。
ホスト検証は`tests/check_sd_log.py`で実際のCコードを実行し、時刻パケット、
2日間の時刻継続（模擬稼働時間）、閏日、全センサーCSV、符号・単位変換、
64ビット識別情報、欠測・未同期、パケット不正・容量不足を確認する。

参照：[Zephyr Disk Access](https://docs.zephyrproject.org/latest/services/storage/disk/access.html)、
[SDHC SPI binding](https://docs.zephyrproject.org/latest/build/dts/api/bindings/sdhc/zephyr%2Csdhc-spi-slot.html)。
実装はインストール済みNCS v3.4.1のZephyr API・Kconfigに合わせた。

## 実機確認（2026-10-04）

通常構成をJ-Link `69730357`へバックアップ後に書き込み済み。
同じRead/Notify characteristicのWrite属性を確認し、Mac CoreBluetoothから
UTC時刻を送信してATT Write Responseを受け取った。
切断後も毎秒の測定が続き、15回のNotifyをWebアプリと同じデコーダーで検証した。
ブラウザーの時刻送信・同期表示・送信失敗時の受信継続はPlaywrightで確認した。
実機へのブラウザー直接接続は未検証。
SD未挿入時の`fs_mount=-5`は、基板へFAT32カードを挿して解消した。
`OUTDOOR/00000001.CSV`への60件単位の書き込みと`fs_sync()`成功を確認した。
そのカードをPCへ移し、実ファイル88147 bytes・240行・95列を読み取って検証済み。
全240行の時刻は同期済みで、保存区間は日本時間20:42:00.236〜20:48:52.236。
同じ起動中の日時と稼働時間の差分は一定で、記録された測定は1秒間隔。
SD未挿入中にバッファが埋まった区間には173サンプルの欠測がある
（sequence 180→354）。STCC4の`-EAGAIN`2回は測定列が空欄となり、
他センサーの測定値は残っている。
保存された14サンプル・1148フィールドは、実際のBLEパケットを
Webアプリの`src/protocol.ts`でデコードした値とすべて一致した。
PCから読めたため、診断用の読み戻し・RTTダンプは通常構成には追加していない。
ログは`.local/sd_verified_rtt.log`、`.local/ble_sd_clock_final.jsonl`、
`.local/ble_sd_clock_validation.json`、`.local/sd_flash_final.log`。

SDファイルの検証コマンド（カードを変更しない）：

```sh
python3 outdoor/firmware/tests/check_sd_card_csv.py /Volumes/BOOT/OUTDOOR/00000001.CSV
```

検証用コピーと結果は`.local/sd_00000001_verified.csv`、
`.local/sd_card_csv_validation.json`、`.local/sd_ble_comparison.json`に保存した。
SHA-256: `b41a931bd97ec9a2dd35fcf86196b10c1baef2bffea67b36e17e5da1311efe2f`。
通常構成への復帰は`.local/sd_normal_restore_flash.log`を参照。

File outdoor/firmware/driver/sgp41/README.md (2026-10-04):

# SGP41 / VOC Index・NOx Index

Sensirion公式Gas Index Algorithm v3.2.0のfixed-point実装を使い、
1秒ごとのSGP41 raw信号をVOC Index・NOx Index（1〜500）へ変換する。
絶対濃度のppm/ppbへの換算ではなく、VOC Indexの標準的な基準は100、NOx Indexの基準は1。
raw値は診断とCSV用に保持する。

公式ソースは`vendor/`へBSD-3-Clauseのライセンスとともに保存し、
revisionを[UPSTREAM.md](vendor/UPSTREAM.md)に固定した。
`gas_indices.c`が2つのアルゴリズム状態と有効フラグを管理する。

起動後の最初の10秒はセンサーのconditioningを行い、NOx rawを使用しない。
アルゴリズムの最初の約45秒も暖機扱いにする。
有効なraw値を連続して1Hzで取得すると、VOCは初回から47回目、
NOxはconditioning後の47回目（起動から約57回目）にIndexが有効になる。
実機では最初のVOC rawが0だったため、VOCは起動から48回目に有効になった。
暖機中はIndex値を0、有効フラグをfalseにし、Webでは`—`と表示する。

CRCが通った測定だけ処理する。間隔が1500msを超える欠測、同一時刻、
時刻の巻き戻りでは両方の履歴をリセットする。
範囲外rawは該当アルゴリズムをリセットし、NOx conditioning中もNOx履歴をリセットする。
停止・再初期化では両方を初期化する。

`tests/check_gas_indices.py`は公式Cソースとこのアダプターをホストで実行し、
conditioning、暖機、基準値、信号変化への反応、欠測、無効入力を確認する。
2026-10-04に実機へ書き込み、暖機後のVOC/NOx Indexと
STCC4/SHT45の温湿度を用いた補償をRTTで確認。
実際のBLE Read/NotifyをWebアプリのデコーダーで検証した。

- [Sensirion Gas Index Algorithm](https://github.com/Sensirion/gas-index-algorithm/tree/2ef9f13d225e8a0dedd3ff42dd229af4dbb1aae4)
- [SGP41 datasheet](../../../../docs/datasheets/Sensirion_Gas_Sensors_Datasheet_SGP41.pdf)

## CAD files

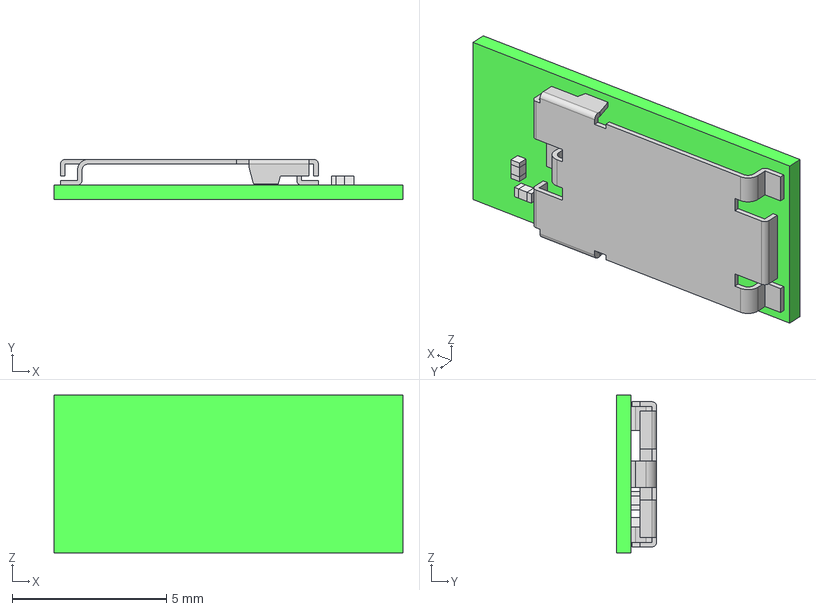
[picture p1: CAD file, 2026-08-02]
card/hardware/3dmodels/BLE_TypeJ2.STEP
11.3 x 1.30 x 5.10 mm
PCB
CASE
____-______O__3 x 2
____-______O__1 x 2
____-______O__2 x 2

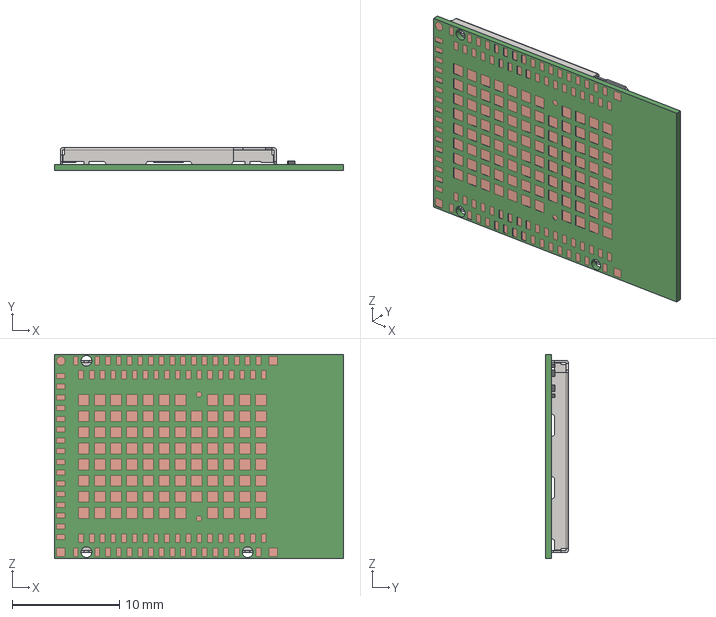
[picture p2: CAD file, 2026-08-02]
card/hardware/3dmodels/WKR612AA1.STEP
26.9 x 2.10 x 19.0 mm
PCB-223023
SC-223023

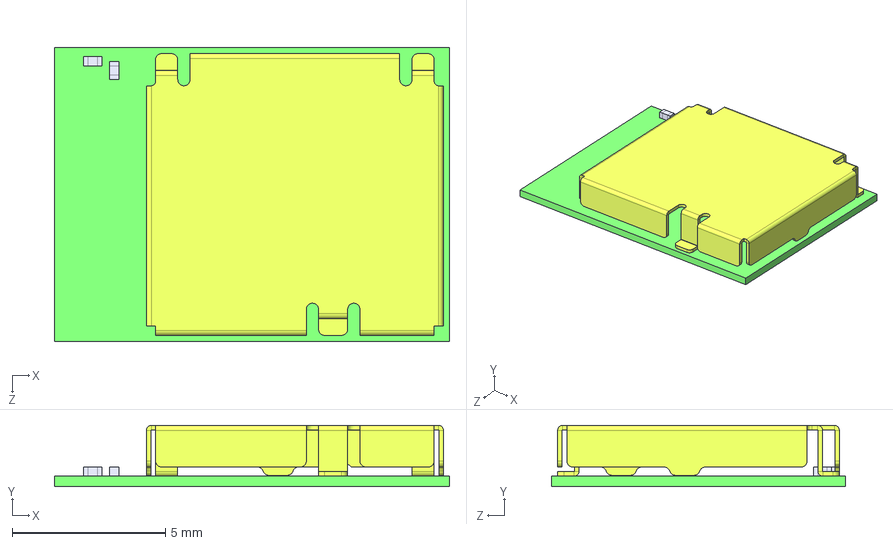
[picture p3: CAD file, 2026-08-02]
card/hardware/3dmodels/BLE_TypeC1.STEP
12.9 x 2.00 x 9.60 mm
2022.04.01_基板
2022.04.04_シールドケース
C1(MK063)
L1(HK0603)

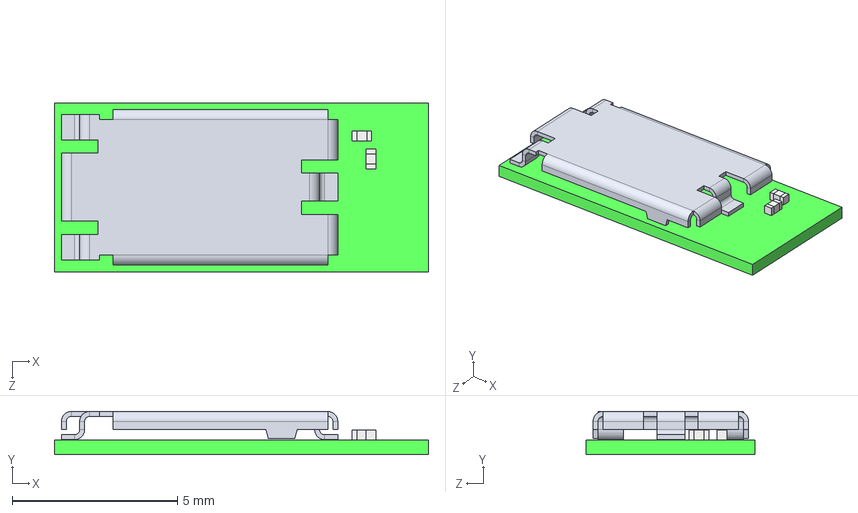
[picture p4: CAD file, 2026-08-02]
card/hardware/3dmodels/BLE_TypeJ1.STEP
11.3 x 1.30 x 5.10 mm
3_BLE小型BLE_MODULE基板（なし） x 2
L x 2
3_BLE小型BLE_MODULE_シールドCase

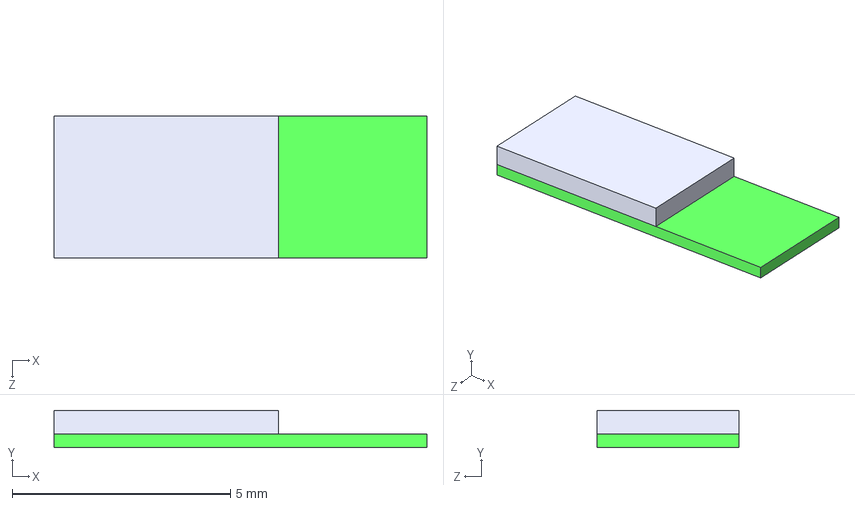
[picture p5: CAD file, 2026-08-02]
card/hardware/3dmodels/BLE_TypeS1.STEP
8.55 x 0.85 x 3.25 mm

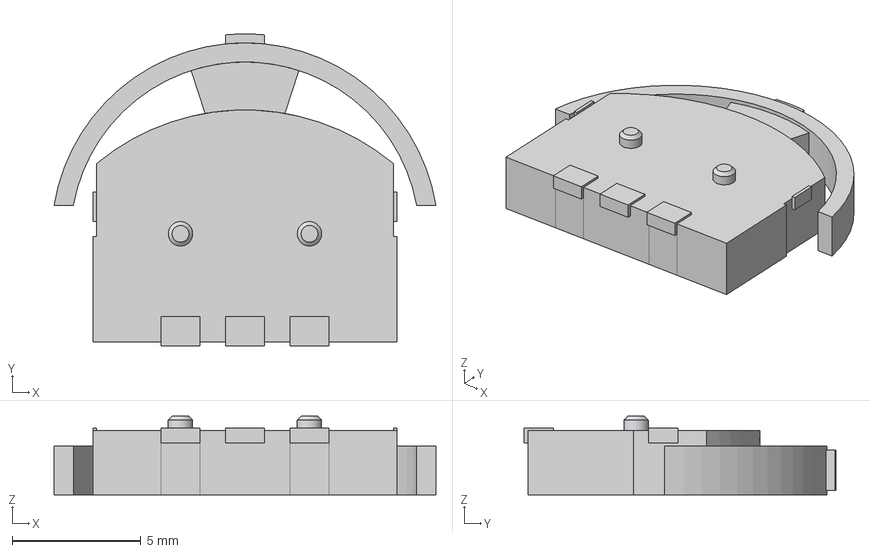
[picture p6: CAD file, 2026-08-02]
card/hardware/3dmodels/LeverSwitch_TMHU27.step
14.8 x 12.1 x 3.05 mm

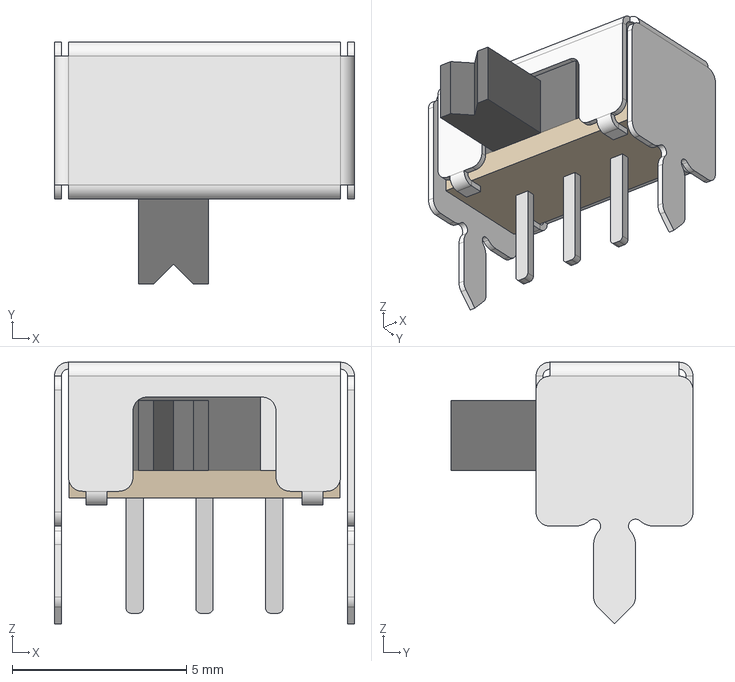
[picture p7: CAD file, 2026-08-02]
card/hardware/3dmodels/SK-12D11VG3.step
8.60 x 6.94 x 7.50 mm

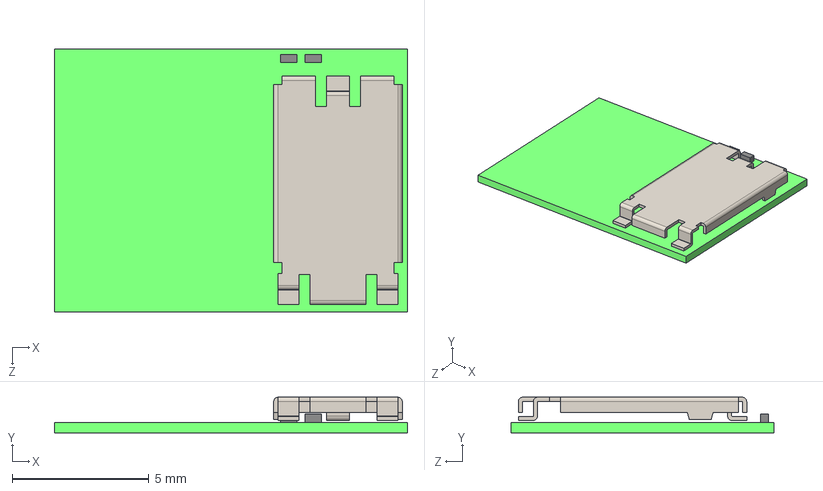
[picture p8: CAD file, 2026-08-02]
card/hardware/3dmodels/BLE_TypeD1.STEP
12.9 x 1.30 x 9.60 mm
9_BLE_小型サイズベースANT拡大MODULE基板_1_2
9_BLE_小型サイズベースANT拡大MODULE_シールドケース_1_2

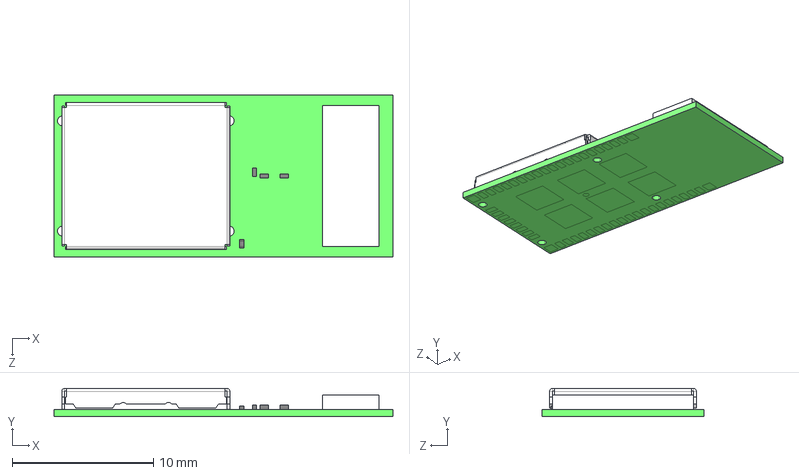
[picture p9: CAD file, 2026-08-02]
card/hardware/3dmodels/WLAN_TypeD1.STEP
24.0 x 2.00 x 11.5 mm

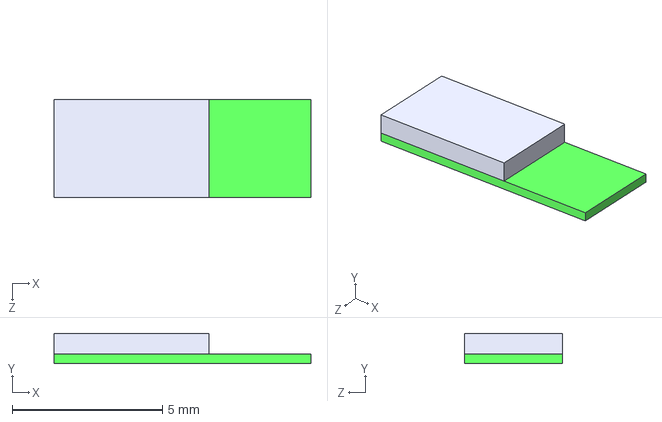
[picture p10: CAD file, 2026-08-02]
card/hardware/3dmodels/BLE_TypeS2.STEP
8.55 x 1.00 x 3.25 mm

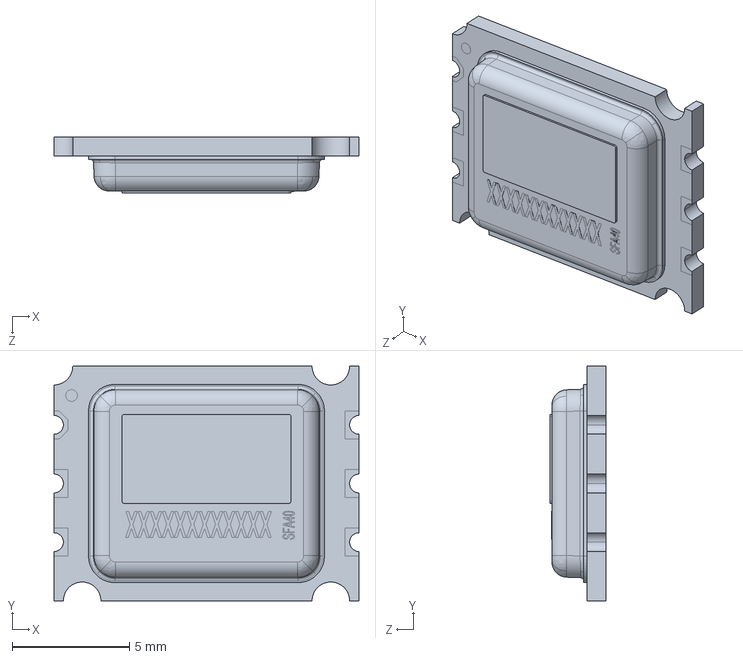
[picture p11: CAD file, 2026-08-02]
card/hardware/3dmodels/STEP_file_SFA40.stp
13.0 x 10.0 x 2.40 mm

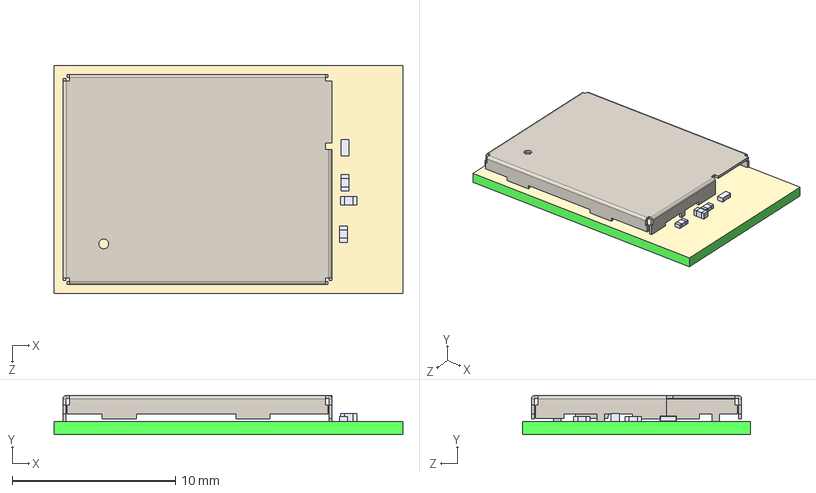
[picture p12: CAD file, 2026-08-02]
card/hardware/3dmodels/WLAN_TypeL1.STEP
21.4 x 2.40 x 14.0 mm
8_88MW300_MODULE基板（なし）
GTC100-KST(シールドケース）
L1、L2(HK1005) x 2
C6(MK105)
R1(MCR01)

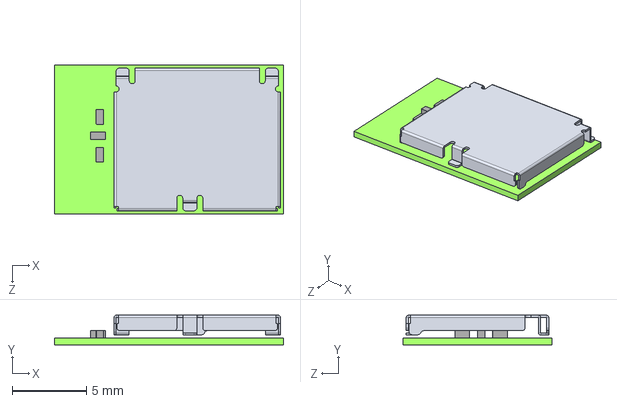
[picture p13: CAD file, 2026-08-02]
card/hardware/3dmodels/BLE_TypeB1.STEP
15.4 x 2.00 x 10.0 mm
4_BLE超大型BLE_MODULE基板
4_BLE超大型BLE_MODULE_シールドCase

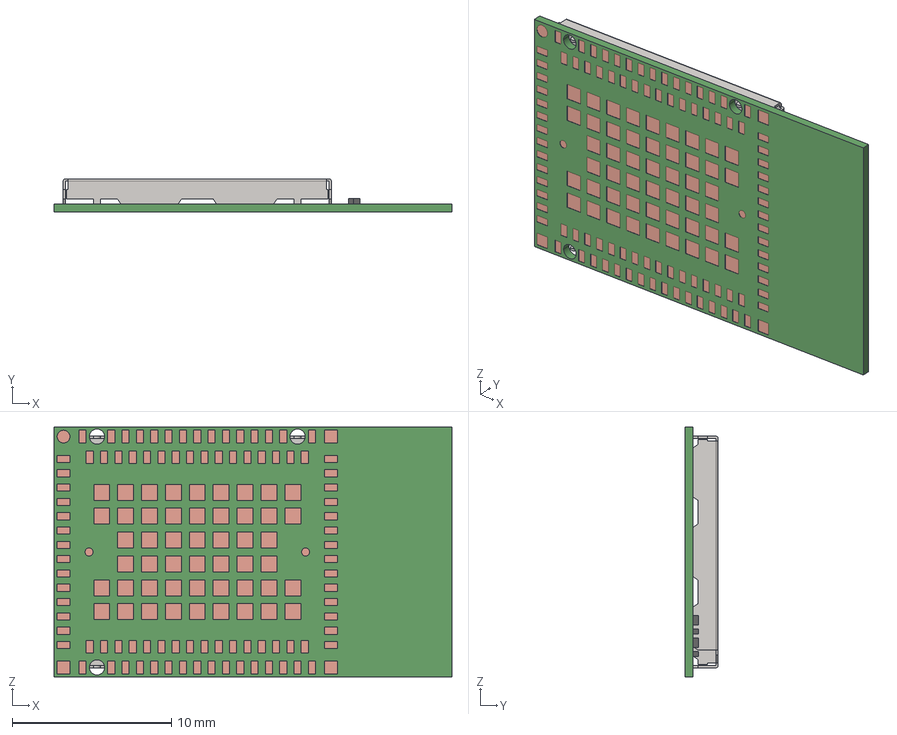
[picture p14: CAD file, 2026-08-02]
card/hardware/3dmodels/WKI611AA1.STEP
25.0 x 2.10 x 15.7 mm
PCB-223052
SC-223052

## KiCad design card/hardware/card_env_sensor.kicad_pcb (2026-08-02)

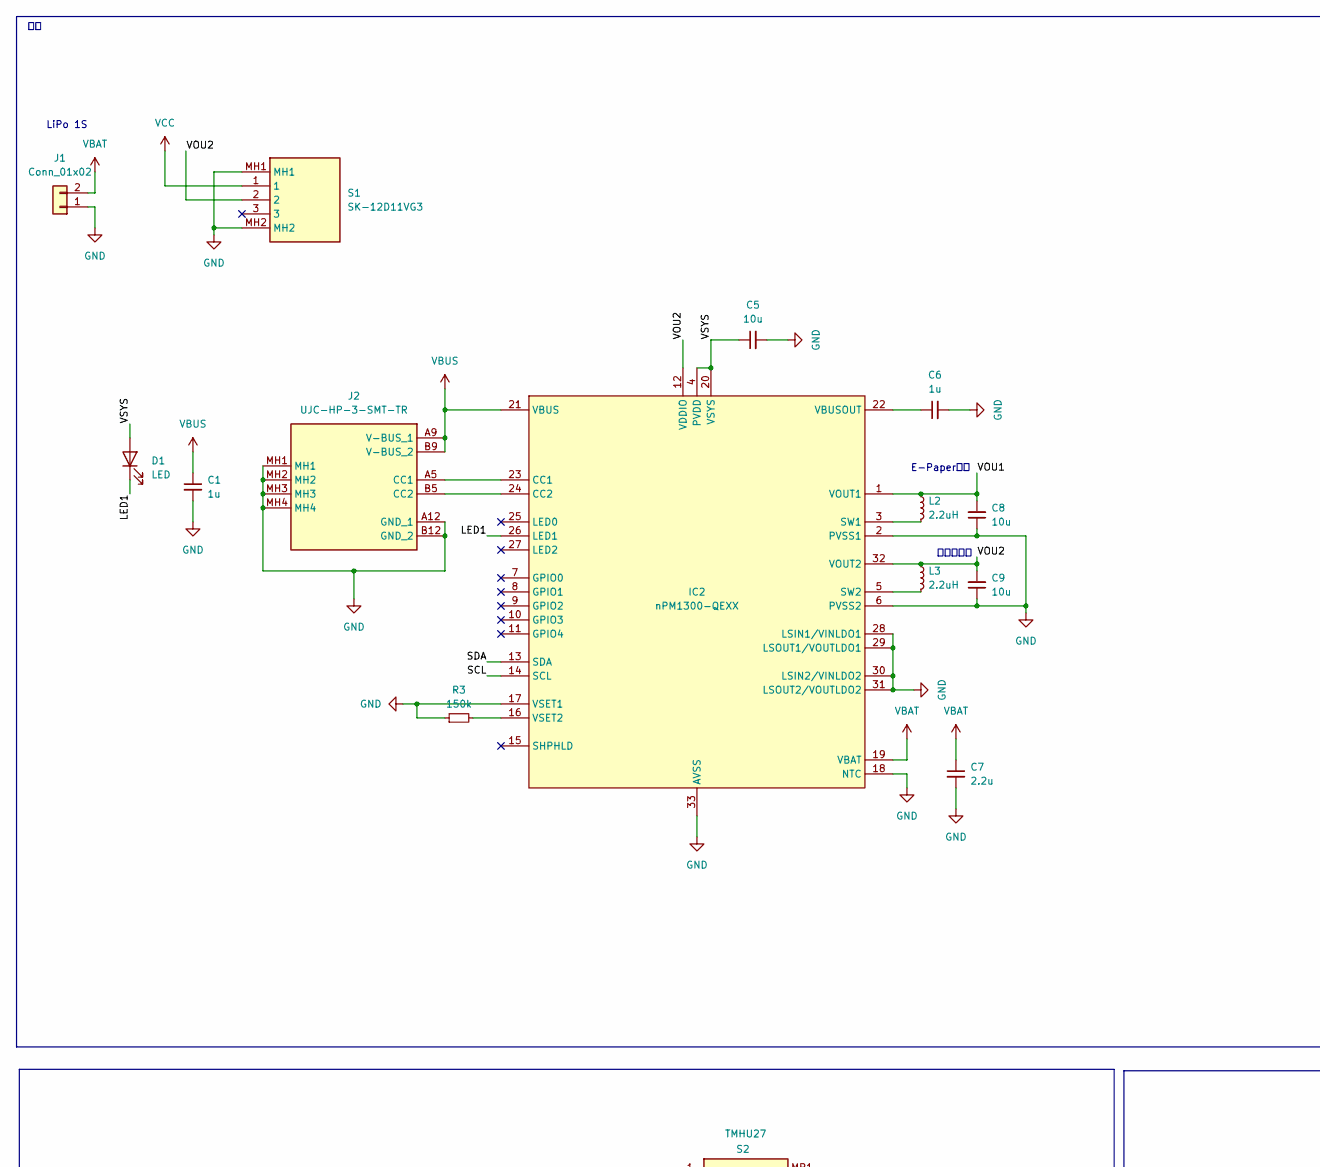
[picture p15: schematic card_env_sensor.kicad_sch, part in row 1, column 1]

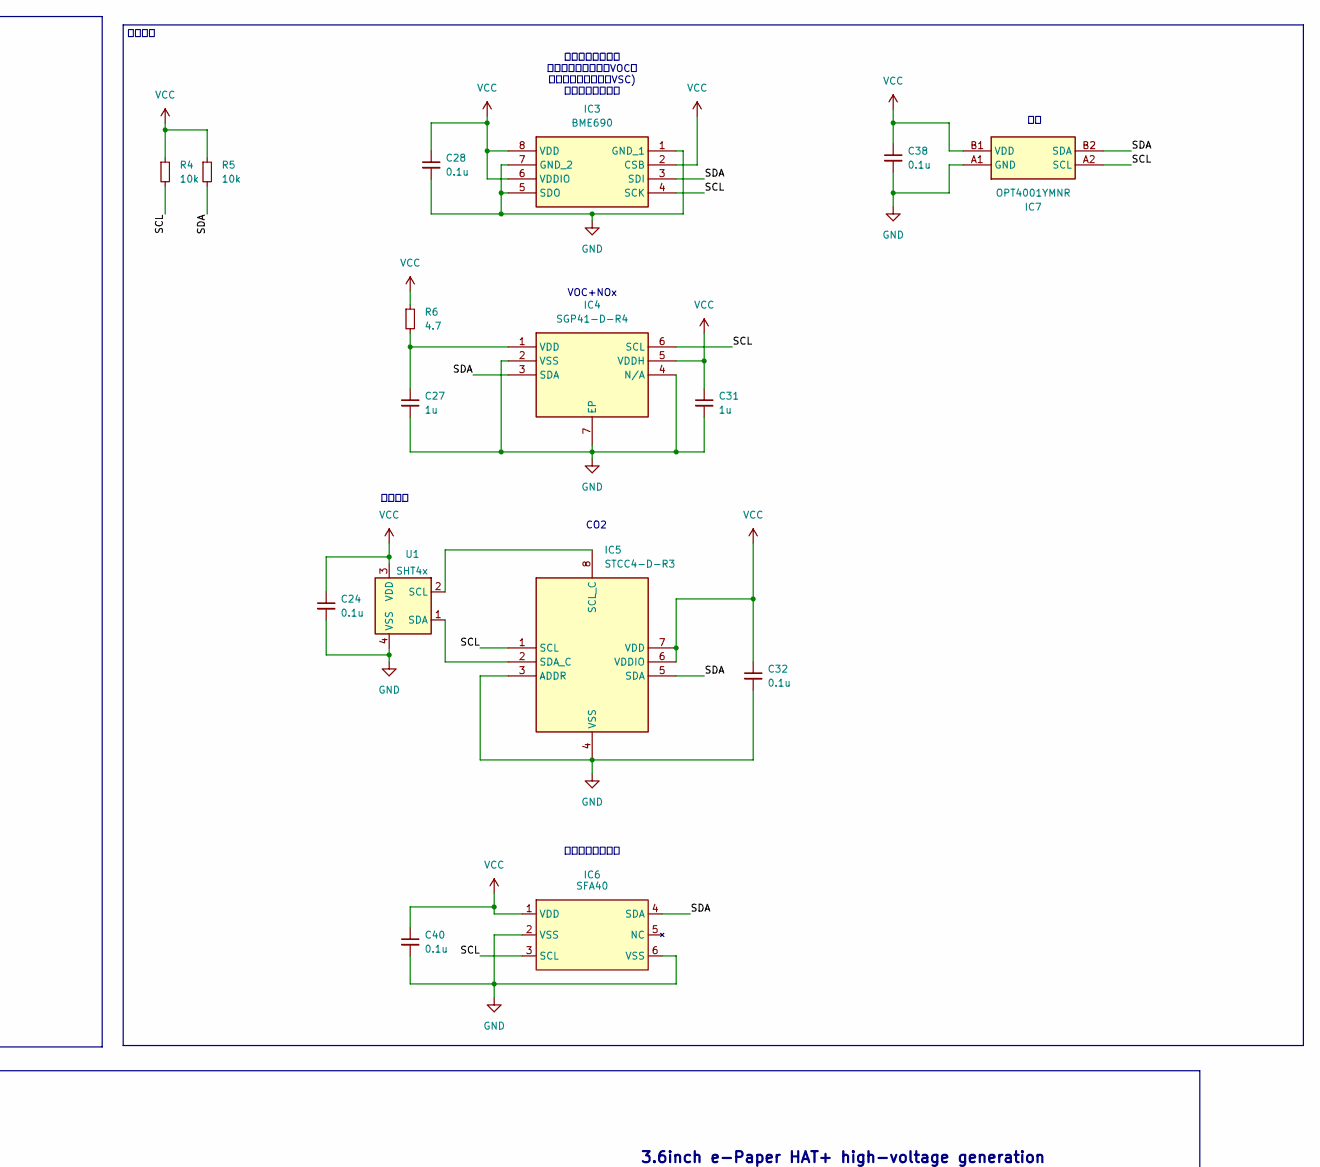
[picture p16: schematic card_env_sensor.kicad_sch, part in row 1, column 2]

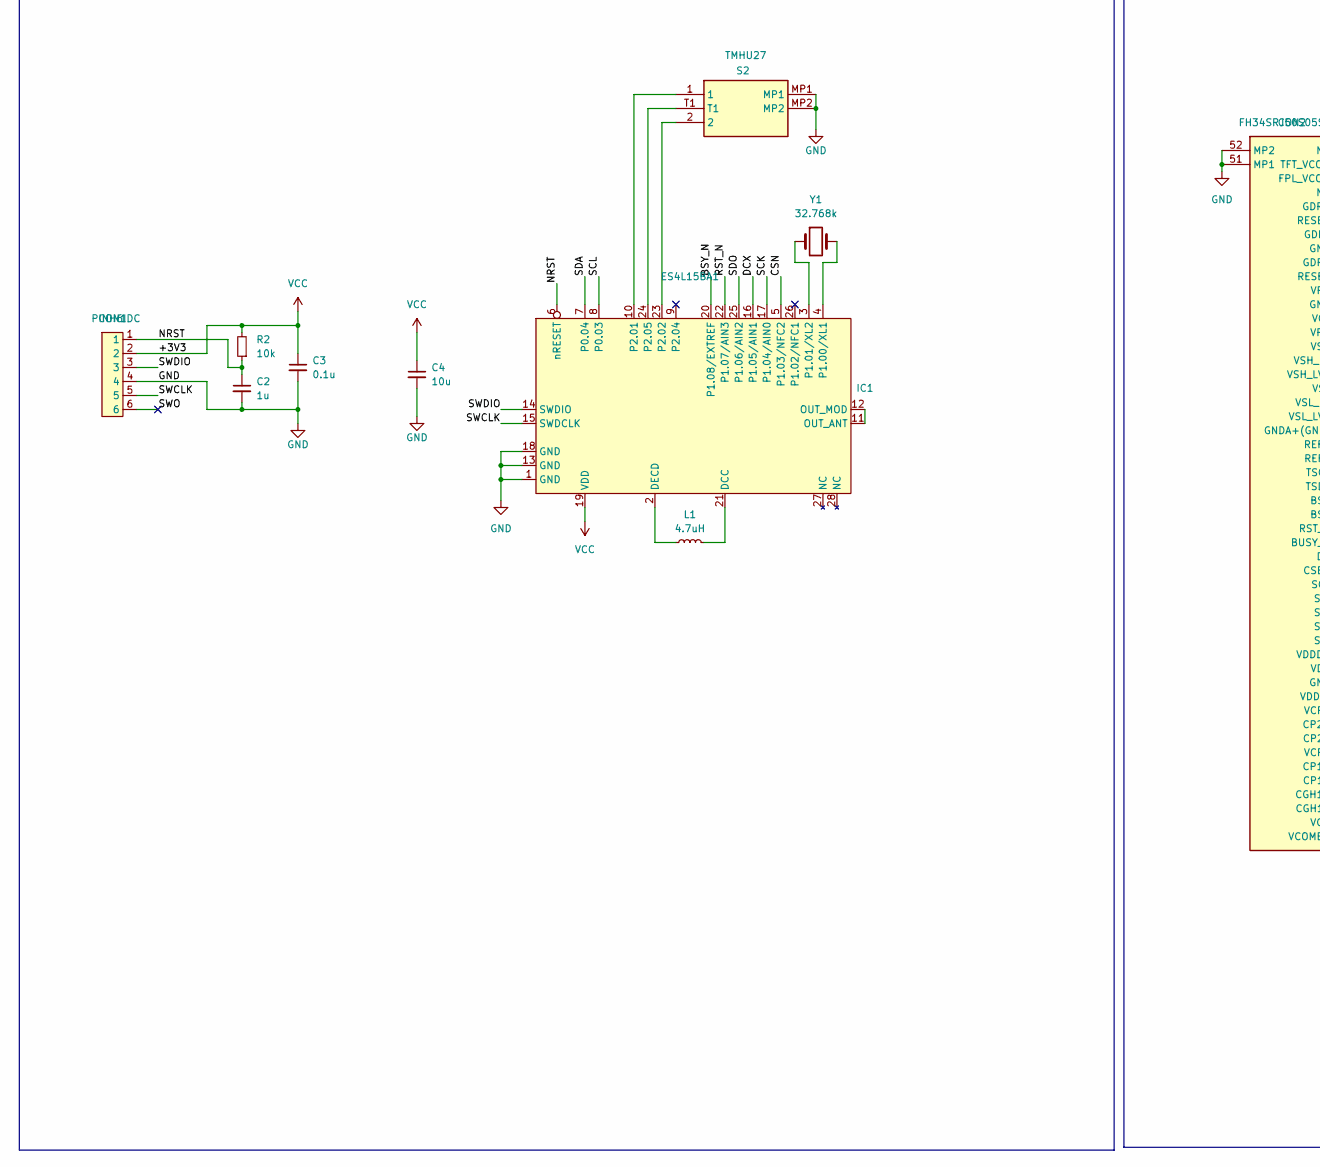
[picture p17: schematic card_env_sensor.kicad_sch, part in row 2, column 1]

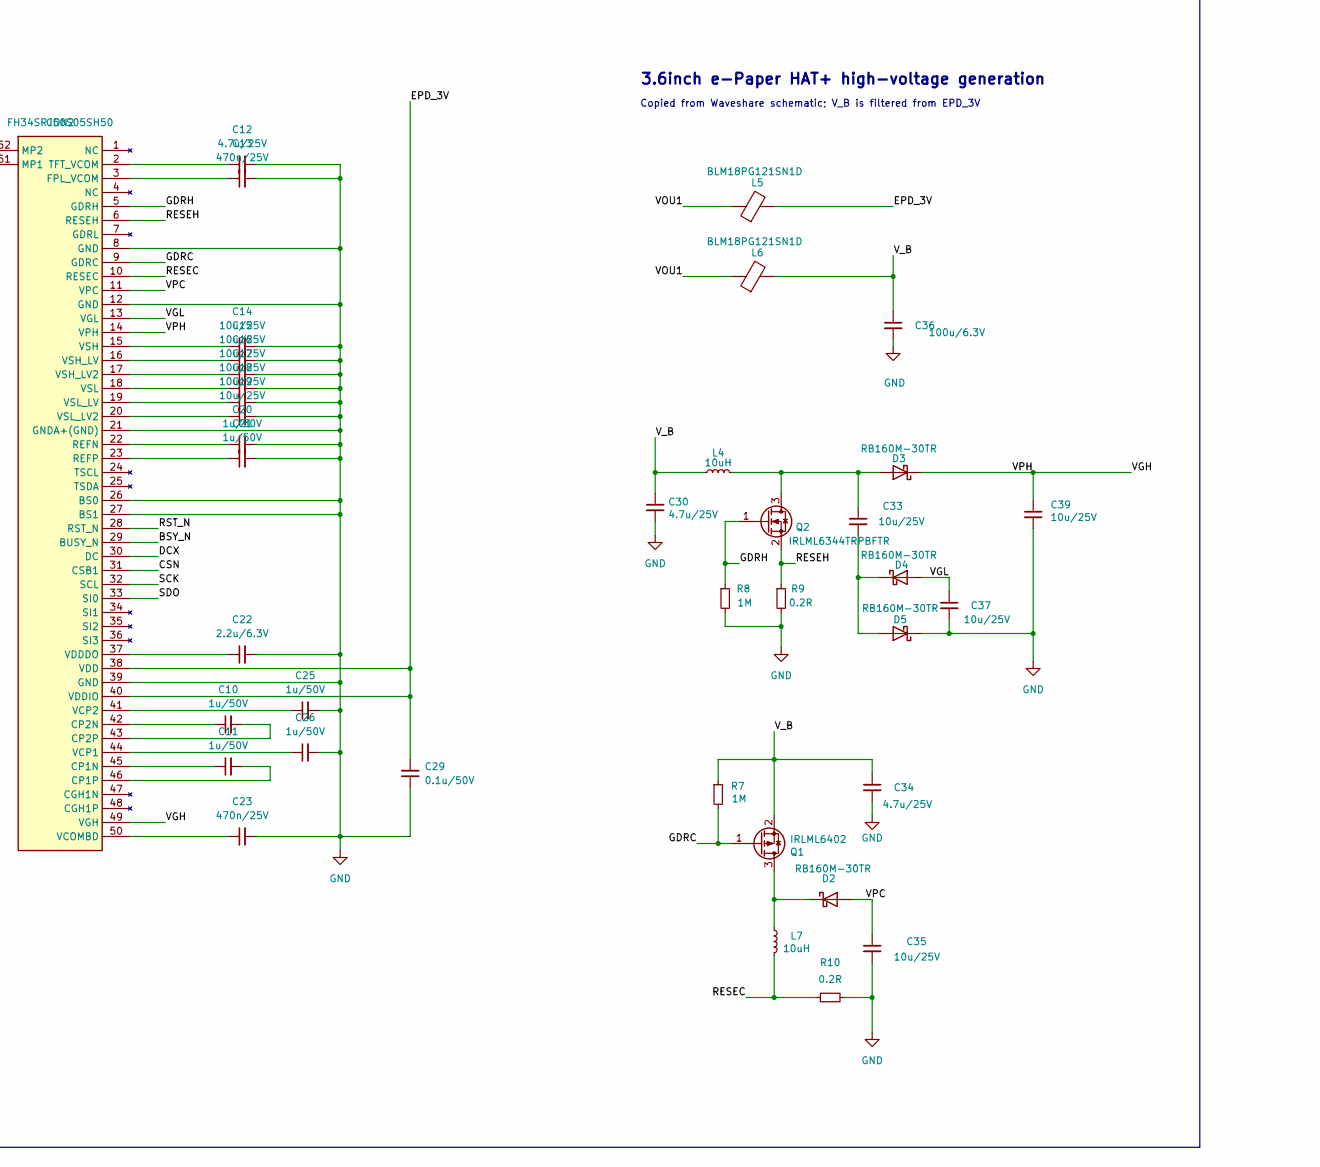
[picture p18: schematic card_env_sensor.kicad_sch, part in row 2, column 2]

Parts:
C1, C2, C6, C27, C31: 1u; C_0402_1005Metric
C3, C24, C28, C32, C38, C40: 0.1u; C_0201_0603Metric
C4, C5, C8, C9: 10u; C_0603_1608Metric
C7: 2.2u; C_0201_0603Metric
C10, C11, C20, C21, C25, C26: 1u/50V; C_0603_1608Metric
C12, C30, C34: 4.7u/25V; C_0805_2012Metric
C13, C23: 470n/25V; C_0603_1608Metric
C14, C15, C16, C17, C18, C19, C33, C35, C37, C39: 10u/25V; C_0603_1608Metric
C22: 2.2u/6.3V; C_0201_0603Metric
C29: 0.1u/50V; C_0201_0603Metric
C36: 100u/6.3V; C_1210_3225Metric
CON1: PINH6IDC
CON2: FH34SRJ50S05SH50
D1: LED; LED_0603_1608Metric
D2, D3, D4, D5: RB160M-30TR; D_SOD-123F
IC1: ES4L15BA1
IC2: nPM1300-QEXX; QFN-32-1EP_5x5mm_P0.5mm_EP3.6x3.6mm_ThermalVias
IC3: BME690; Manufacturer_Part_Number BME690; Mouser Part Number 262-BME690
IC4: SGP41-D-R4; SON80P244X244X95-7N; Manufacturer_Part_Number SGP41-D-R4; Mouser Part Number 403-SGP41-D-R4
IC5: STCC4-D-R3; STCC4DR3; Manufacturer_Part_Number STCC4-D-R3
IC6: SFA40
IC7: OPT4001YMNR; Manufacturer_Part_Number OPT4001YMNR; Mouser Part Number 595-OPT4001YMNR
J1: Conn_01x02; JST_PH_S2B-PH-K_1x02_P2.00mm_Horizontal
J2: UJC-HP-3-SMT-TR; UJCHP3SMTTR; Manufacturer_Part_Number UJC-HP-3-SMT-TR; Mouser Part Number 490-UJC-HP-3-SMT-TR
L1: 4.7uH; L_0603_1608Metric
L2, L3: 2.2uH; L_0603_1608Metric
L4, L7: 10uH; L_0603_1608Metric
L5, L6: BLM18PG121SN1D; L_0603_1608Metric
Q1: IRLML6402; SOT-23
Q2: IRLML6344TRPBFTR; SOT-23
R2, R4, R5: 10k; R_0402_1005Metric
R3: 150k; R_0402_1005Metric
R6: 4.7; R_0402_1005Metric
R7, R8: 1M; R_0402_1005Metric
R9, R10: 0.2R; R_1206_3216Metric
S1: SK-12D11VG3; SK12D11VG3; Manufacturer_Part_Number SK-12D11VG3
S2: TMHU27; Manufacturer_Part_Number TMHU27
U1: SHT4x; Sensirion_DFN-4_1.5x1.5mm_P0.8mm_SHT4x_NoCentralPad
Y1: 32.768k; FC12M327680KDA0

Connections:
/BSY_N: CON2.29 (BUSY_N), IC1.20 (P1.08/EXTREF)
/CSN: CON2.31 (CSB1), IC1.5 (P1.03/NFC2)
/DCX: CON2.30 (DC), IC1.16 (P1.05/AIN1)
/EPD_3V: C29.2, CON2.38 (VDD), CON2.40 (VDDIO), L5.2
/GDRC: CON2.9 (GDRC), Q1.1 (G), R7.2
/GDRH: CON2.5 (GDRH), Q2.1 (G), R8.1
/LED1: D1.1 (K), IC2.26 (LED1)
/NRST: C2.1, CON1.1, IC1.6 (nRESET), R2.1
/RESEC: CON2.10 (RESEC), L7.2, R10.1
/RESEH: CON2.6 (RESEH), Q2.2 (S), R9.1
/RST_N: CON2.28 (RST_N), IC1.22 (P1.07/AIN3)
/SCK: CON2.32 (SCL), IC1.17 (P1.04/AIN0)
/SCL: IC1.8 (P0.03), IC2.14 (SCL), IC3.4 (SCK), IC4.6 (SCL), IC5.1 (SCL), IC6.3 (SCL), IC7.A2 (SCL), R4.2
/SDA: IC1.7 (P0.04), IC2.13 (SDA), IC3.3 (SDI), IC4.3 (SDA), IC5.5 (SDA), IC6.4 (SDA), IC7.B2 (SDA), R5.2
/SDO: CON2.33 (SI0), IC1.25 (P1.06/AIN2)
/SWCLK: CON1.5, IC1.15 (SWDCLK)
/SWDIO: CON1.3, IC1.14 (SWDIO)
/SWO: CON1.6
/VGH: C39.1, CON2.14 (VPH), CON2.49 (VGH), D3.1 (K)
/VGL: C37.1, CON2.13 (VGL), D4.2 (A)
/VOU1: C8.2, IC2.1 (VOUT1), L2.1, L5.1, L6.1
/VOU2: C9.2, IC2.12 (VDDIO), IC2.32 (VOUT2), L3.1, S1.2
/VPC: C35.1, CON2.11 (VPC), D2.2 (A)
/VSYS: C5.1, D1.2 (A), IC2.4 (PVDD), IC2.20 (VSYS)
/V_B: C30.1, C34.1, C36.1, L4.1, L6.2, Q1.2 (S), R7.1
GND: C1.2, C2.2, C3.2, C4.2, C5.2, C6.2, C7.2, C8.1, C9.1, C12.2, C13.2, C14.2, C15.2, C16.2, C17.2, C18.2, C19.2, C20.2, C21.2, C22.2, C23.2, C24.2, C25.2, C26.2, C27.2, C28.2, C29.1, C30.2, C31.2, C32.2, C34.2, C35.2, C36.2, C37.2, C38.2, C39.2, C40.2, CON1.4, CON2.8 (GND), CON2.12 (GND), CON2.21 (GNDA+(GND)), CON2.26 (BS0), CON2.27 (BS1), CON2.39 (GND), CON2.51 (MP1), CON2.52 (MP2), D5.1 (K), IC1.1 (GND), IC1.13 (GND), IC1.18 (GND), IC2.2 (PVSS1), IC2.6 (PVSS2), IC2.17 (VSET1), IC2.18 (NTC), IC2.28 (LSIN1/VINLDO1), IC2.29 (LSOUT1/VOUTLDO1), IC2.30 (LSIN2/VINLDO2), IC2.31 (LSOUT2/VOUTLDO2), IC2.33 (AVSS), IC3.1 (GND_1), IC3.5 (SDO), IC3.7 (GND_2), IC4.2 (VSS), IC4.4 (N/A), IC4.7 (EP), IC5.3 (ADDR), IC5.4 (VSS), IC6.2 (VSS), IC6.6 (VSS), IC7.A1 (GND), J1.1, J2.A12 (GND_1), J2.B12 (GND_2), J2.MH1, J2.MH2, J2.MH3, J2.MH4, R3.1, R8.2, R9.2, R10.2, S1.MH1, S1.MH2, S2.MP1, S2.MP2, U1.4 (VSS)
unnamed: C11.1, CON2.45 (CP1N)
unnamed: C11.2, CON2.46 (CP1P)
unnamed: C10.1, CON2.42 (CP2N)
unnamed: C10.2, CON2.43 (CP2P)
unnamed: C13.1, CON2.3 (FPL_VCOM)
unnamed: C20.1, CON2.22 (REFN)
unnamed: C21.1, CON2.23 (REFP)
unnamed: C12.1, CON2.2 (TFT_VCOM)
unnamed: C23.1, CON2.50 (VCOMBD)
unnamed: C26.1, CON2.44 (VCP1)
unnamed: C25.1, CON2.41 (VCP2)
unnamed: C22.1, CON2.37 (VDDDO)
unnamed: C14.1, CON2.15 (VSH)
unnamed: C16.1, CON2.17 (VSH_LV2)
unnamed: C15.1, CON2.16 (VSH_LV)
unnamed: C17.1, CON2.18 (VSL)
unnamed: C19.1, CON2.20 (VSL_LV2)
unnamed: C18.1, CON2.19 (VSL_LV)
unnamed: D2.1 (K), L7.1, Q1.3 (D)
unnamed: C33.1, D3.2 (A), L4.2, Q2.3 (D)
unnamed: C33.2, D4.1 (K), D5.2 (A)
unnamed: IC1.21 (DCC), L1.2
unnamed: IC1.2 (DECD), L1.1
unnamed: IC1.11 (OUT_ANT), IC1.12 (OUT_MOD)
unnamed: IC1.4 (P1.00/XL1), Y1.2
unnamed: IC1.3 (P1.01/XL2), Y1.1
unnamed: IC1.10 (P2.01), S2.1
unnamed: IC1.23 (P2.02), S2.2
unnamed: IC1.24 (P2.05), S2.T1
unnamed: IC2.23 (CC1), J2.A5 (CC1)
unnamed: IC2.24 (CC2), J2.B5 (CC2)
unnamed: IC2.3 (SW1), L2.2
unnamed: IC2.5 (SW2), L3.2
unnamed: C6.1, IC2.22 (VBUSOUT)
unnamed: IC2.16 (VSET2), R3.2
unnamed: C27.1, IC4.1 (VDD), R6.2
unnamed: IC5.8 (SCL_C), U1.2 (SCL)
unnamed: IC5.2 (SDA_C), U1.1 (SDA)
VBAT: C7.1, IC2.19 (VBAT), J1.2
VBUS: C1.1, IC2.21 (VBUS), J2.A9 (V-BUS_1), J2.B9 (V-BUS_2)
VCC: C3.1, C4.1, C24.1, C28.1, C31.1, C32.1, C38.1, C40.1, CON1.2, IC1.19 (VDD), IC3.2 (CSB), IC3.6 (VDDIO), IC3.8 (VDD), IC4.5 (VDDH), IC5.6 (VDDIO), IC5.7 (VDD), IC6.1 (VDD), IC7.B1 (VDD), R2.2, R4.1, R5.1, R6.1, S1.1, U1.3 (VDD)

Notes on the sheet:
CO2
VOC+NOx
センサー
メイン電源
LiPo 1S
3.6inch e-Paper HAT+ high-voltage generation
Copied from Waveshare schematic; V_B is filtered from EPD_3V
温度、気圧、湿度 揮発性有機化合物（VOC） 揮発性硫黄化合物（VSC) 一酸化炭素、水素
E-Paper電源
温度湿度
ホルムアルデヒド

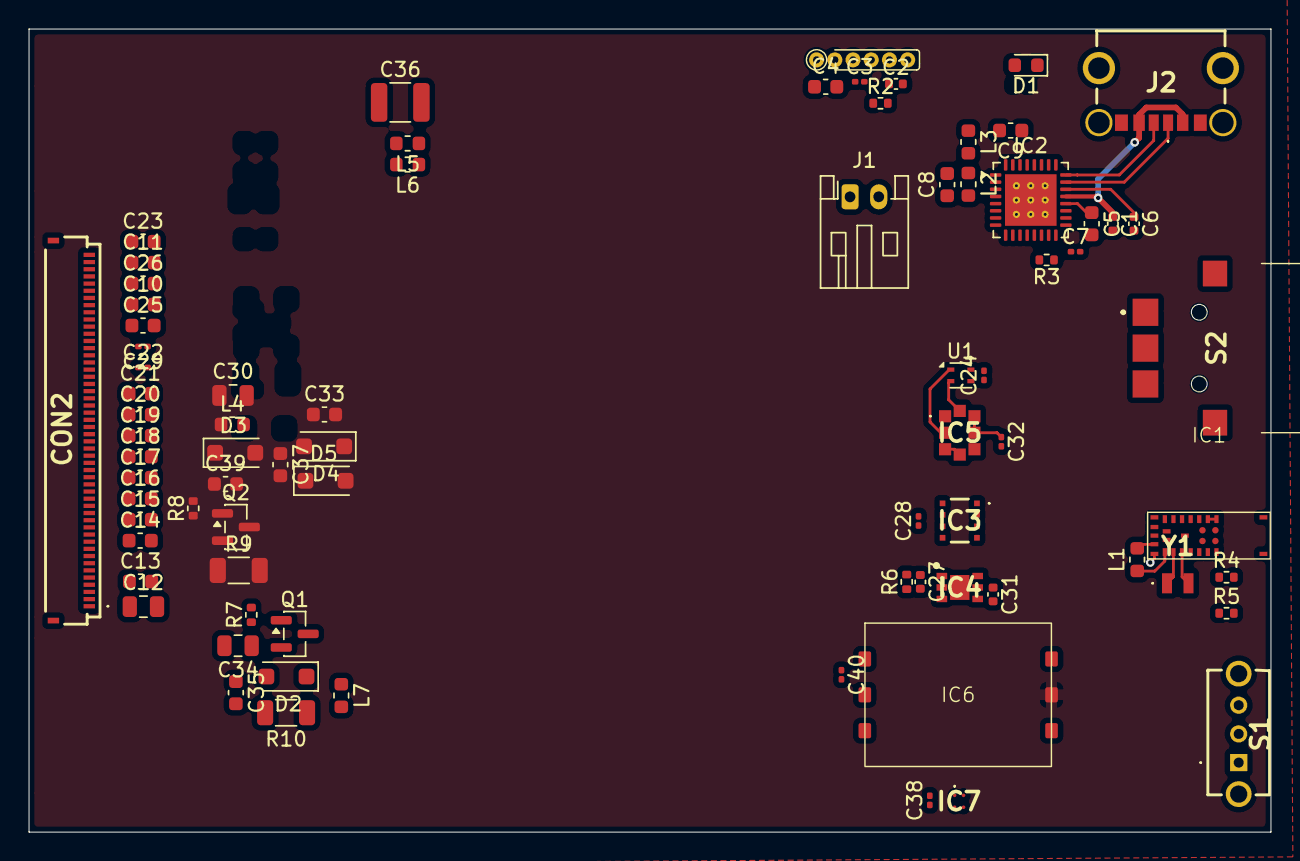
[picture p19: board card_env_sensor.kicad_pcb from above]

Board: 2 copper layers, 86.6 x 56.0 mm, 78 parts (0 on the bottom side), 66 nets.

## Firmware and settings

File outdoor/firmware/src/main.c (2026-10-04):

#include <buzzer.h>
#if defined(CONFIG_APP_BLE) || defined(CONFIG_APP_SD_LOG)
#include <telemetry.h>
#if defined(CONFIG_APP_SD_LOG)
#include <sd_log.h>
#endif
#endif
#if defined(CONFIG_APP_SENSOR_READ)
#include <bme690.h>
#if defined(CONFIG_APP_BMV080)
#include <bmv080_driver.h>
#endif
#if defined(CONFIG_APP_AS3935)
#include <as3935.h>
#endif
#if defined(CONFIG_APP_SFA40)
#include <sfa40.h>
#endif
#include <opt4001.h>
#include <sgp41.h>
#include <stcc4.h>
#endif

#include <errno.h>
#include <zephyr/drivers/gpio.h>
#include <zephyr/drivers/i2c.h>
#include <zephyr/kernel.h>
#include <zephyr/sys/printk.h>

#if defined(CONFIG_APP_I2C_SCAN)
static int scan_i2c(void)
{
	const struct device *bus = DEVICE_DT_GET(DT_ALIAS(i2c_sensors));
	unsigned int found = 0;
	uint8_t unused = 0;
	struct i2c_msg probe = {
		.buf = &unused,
		.len = 0,
		.flags = I2C_MSG_WRITE | I2C_MSG_STOP,
	};

	if (!device_is_ready(bus)) {
		printk("ERROR: I2C controller is not ready\n");
		return -ENODEV;
	}

	/* Allow the powered sensors to finish startup before probing. */
	k_msleep(1000);
	int recovery = i2c_recover_bus(bus);

	if (recovery != 0) {
		const struct device *gpio = DEVICE_DT_GET(DT_NODELABEL(gpio0));

		printk("ERROR: I2C bus recovery: %d; SCL=%d SDA=%d\n", recovery,
		       gpio_pin_get(gpio, 3), gpio_pin_get(gpio, 4));
		return recovery;
	}
	printk("I2C SCAN START: %s, SCL P0.03, SDA P0.04, %u Hz, 7-bit 0x01..0x03 + 0x08..0x77\n",
	       bus->name, DT_PROP(DT_ALIAS(i2c_sensors), clock_frequency));
	for (uint16_t address = 0x01; address <= 0x77; address++) {
		/* AS3935 uses 0x01..0x03; skip general call and other reserved IDs. */
		if (address > 0x03 && address < 0x08) {
			continue;
		}
		/* Address + STOP only: no sensor command or register data. */
		int err = i2c_transfer(bus, &probe, 1, address);

		if (err == 0) {
			printk("I2C FOUND: 0x%02x\n", address);
			found++;
		} else if (err != -EIO && err != -ENXIO) {
			printk("ERROR: I2C probe 0x%02x failed: %d; scan aborted\n", address, err);
			return err;
		}
		k_msleep(2);
	}
	printk("I2C SCAN DONE: %u device(s)\n", found);
	return 0;
}
#endif

#if defined(CONFIG_APP_SENSOR_READ)
static int init_errors[7];
static bool opt_ready;
static bool sgp_ready;
static bool stcc_ready;
static bool bme_ready;
#if defined(CONFIG_APP_BMV080)
static bool bmv_ready;
#endif
#if defined(CONFIG_APP_AS3935)
static bool lightning_ready;
#endif
#if defined(CONFIG_APP_SFA40)
static bool hcho_ready;
#endif

static bool report_init(const char *name, int err)
{
	if (err != 0) {
		printk("ERROR: %s init failed: %d\n", name, err);
		return false;
	}
	printk("%s READY\n", name);
	return true;
}

static void print_milli(int32_t value)
{
	uint32_t magnitude = value < 0 ? (uint32_t)-(int64_t)value : (uint32_t)value;

	printk("%s%u.%03u", value < 0 ? "-" : "", magnitude / 1000, magnitude % 1000);
}

static void read_sensors(uint32_t sequence)
{
#if defined(CONFIG_APP_BLE) || defined(CONFIG_APP_SD_LOG)
	struct telemetry_sample frame = {
		.sequence = sequence,
		.uptime_ms = k_uptime_get(),
		.enabled_mask = 0x0f,
		.opt4001.error = init_errors[0],
		.bme690.error = init_errors[1],
		.sgp41.error = init_errors[2],
		.stcc4.error = init_errors[3],
	};
#if defined(CONFIG_APP_BMV080)
	frame.enabled_mask |= 0x10;
	frame.bmv080.error = init_errors[4];
#endif
#if defined(CONFIG_APP_AS3935)
	frame.enabled_mask |= 0x20;
	frame.as3935.error = init_errors[5];
#endif
#if defined(CONFIG_APP_SFA40)
	frame.enabled_mask |= 0x40;
	frame.sfa40.error = init_errors[6];
#endif
#else
	ARG_UNUSED(sequence);
#endif
	int32_t compensation_temp = 25000;
	int32_t compensation_rh = 50000;
	const char *compensation_source = "default";
	int err;

	if (opt_ready) {
		struct opt4001_sample sample;

		err = opt4001_read(&sample);
#if defined(CONFIG_APP_BLE) || defined(CONFIG_APP_SD_LOG)
		frame.opt4001.error = err;
		if (err == 0) { frame.opt4001.value = sample; }
#endif
		if (err == 0) {
			printk("OPT4001: lux=");
			print_milli(sample.millilux);
			printk(" mantissa=%u exponent=%u counter=%u id=0x%04x\n",
			       sample.mantissa, sample.exponent, sample.counter, sample.device_id);
		} else {
			printk("ERROR: OPT4001 read: %d\n", err);
		}
	}
	if (bme_ready) {
		struct bme690_sample sample;

		err = bme690_read(&sample);
#if defined(CONFIG_APP_BLE) || defined(CONFIG_APP_SD_LOG)
		frame.bme690.error = err;
		if (err == 0) { frame.bme690.value = sample; }
#endif
		if (err == 0) {
			compensation_temp = sample.temperature_mc;
			compensation_rh = sample.humidity_mpercent;
			compensation_source = "BME690";
			printk("BME690: temp_C=");
			print_milli(sample.temperature_mc);
			printk(" rh_pct=");
			print_milli(sample.humidity_mpercent);
			printk(" pressure_Pa=%u gas_ohm=%u gas_valid=%u heater_stable=%u "
			       "status=0x%02x meas=%u gas_index=%u res_heat=%u idac=%u "
			       "gas_wait=%u chip=0x%02x variant=%u\n",
			       sample.pressure_pa, sample.gas_resistance_ohm, sample.gas_valid,
			       sample.heater_stable, sample.status, sample.measurement_index,
			       sample.gas_index, sample.heater_resistance, sample.heater_current,
			       sample.gas_wait, sample.chip_id, sample.variant_id);
		} else {
			printk("ERROR: BME690 read: %d\n", err);
		}
	}
	if (stcc_ready) {
		struct stcc4_sample sample;

		err = stcc4_read(&sample);
#if defined(CONFIG_APP_BLE) || defined(CONFIG_APP_SD_LOG)
		frame.stcc4.error = err;
		if (err == 0) { frame.stcc4.value = sample; }
#endif
		if (err == 0) {
			compensation_temp = sample.temperature_mc;
			compensation_rh = sample.humidity_mpercent;
			compensation_source = "STCC4/SHT45";
			printk("STCC4: co2_ppm=%d status=0x%04x product=0x%08x serial=%016llx\n",
			       sample.co2_ppm, sample.status, sample.product_id,
			       (unsigned long long)sample.serial_number);
			printk("SHT45: via=STCC4 temp_C=");
			print_milli(sample.temperature_mc);
			printk(" rh_pct=");
			print_milli(sample.humidity_mpercent);
			printk(" raw_t=%u raw_rh=%u\n", sample.raw_temperature, sample.raw_humidity);
		} else {
			printk("ERROR: STCC4 read: %d\n", err);
		}
	}
	if (sgp_ready) {
		struct sgp41_sample sample;

		err = sgp41_read(compensation_temp, compensation_rh, &sample);
#if defined(CONFIG_APP_BLE) || defined(CONFIG_APP_SD_LOG)
		frame.sgp41.error = err;
		if (err == 0) { frame.sgp41.value = sample; }
#endif
		if (err == 0) {
			printk("SGP41: raw_voc=%u raw_nox=%u nox_valid=%u conditioning=%u "
			       "voc_index=%u voc_index_valid=%u nox_index=%u nox_index_valid=%u "
			       "comp=%s temp_ticks=%u rh_ticks=%u "
			       "self_test=0x%04x serial=%012llx\n",
			       sample.raw_voc, sample.raw_nox, sample.nox_valid, sample.conditioning,
			       sample.voc_index, sample.voc_index_valid, sample.nox_index, sample.nox_index_valid,
			       sample.conditioning ? "default" : compensation_source, sample.temperature_ticks,
			       sample.humidity_ticks, sample.self_test,
			       (unsigned long long)sample.serial_number);
		} else {
			printk("ERROR: SGP41 read: %d\n", err);
		}
	}
#if defined(CONFIG_APP_BMV080)
	if (bmv_ready) {
		struct bmv080_sample sample;

		err = bmv080_driver_read(&sample);
#if defined(CONFIG_APP_BLE) || defined(CONFIG_APP_SD_LOG)
		frame.bmv080.error = err;
		if (err == 0) { frame.bmv080.value = sample; }
#endif
		if (err == 0) {
			printk("BMV080: pm1_ug_m3=");
			print_milli(sample.pm1_mass_milliug_m3);
			printk(" pm2_5_ug_m3=");
			print_milli(sample.pm2_5_mass_milliug_m3);
			printk(" pm10_ug_m3=");
			print_milli(sample.pm10_mass_milliug_m3);
			printk(" pm1_particles_cm3=");
			print_milli(sample.pm1_number_milliparticles_cm3);
			printk(" pm2_5_particles_cm3=");
			print_milli(sample.pm2_5_number_milliparticles_cm3);
			printk(" pm10_particles_cm3=");
			print_milli(sample.pm10_number_milliparticles_cm3);
			printk(" obstructed=%u outside_range=%u runtime_ms=%llu seq=%u "
			       "age_ms=%u fresh=%u\n", sample.is_obstructed,
			       sample.is_outside_measurement_range, (unsigned long long)sample.runtime_ms,
			       sample.sequence, sample.age_ms, sample.fresh);
		} else if (err == -EAGAIN) {
			printk("BMV080: waiting for first SDK output\n");
		} else {
			printk("ERROR: BMV080 read: %d\n", err);
		}
	}
#endif
#if defined(CONFIG_APP_SFA40)
	if (hcho_ready) {
		struct sfa40_sample sample;

		err = sfa40_read(&sample);
#if defined(CONFIG_APP_BLE) || defined(CONFIG_APP_SD_LOG)
		frame.sfa40.error = err;
		if (err == 0) { frame.sfa40.value = sample; }
#endif
		if (err == 0) {
			printk("SFA40: hcho_ppb=");
			print_milli(sample.hcho_millippb);
			printk(" temp_C=");
			print_milli(sample.temperature_mc);
			printk(" rh_pct=");
			print_milli(sample.humidity_mpercent);
			printk(" ready=%u within_spec=%u status=0x%02x raw_hcho=%u "
			       "raw_t=%u raw_rh=%u product=0x%08x serial=%012llx\n",
			       sample.ready, sample.within_specification, sample.status,
			       sample.raw_hcho, sample.raw_temperature, sample.raw_humidity,
			       sample.product_id, (unsigned long long)sample.serial_number);
		} else {
			printk("ERROR: SFA40 read: %d\n", err);
		}
	}
#endif
#if defined(CONFIG_APP_AS3935)
	if (lightning_ready) {
		struct as3935_sample sample;

		err = as3935_read(&sample);
#if defined(CONFIG_APP_BLE) || defined(CONFIG_APP_SD_LOG)
		frame.as3935.error = err;
		if (err == 0) { frame.as3935.value = sample; }
#endif
		if (err == 0) {
			printk("AS3935: irq=0x%02x lightning=%u noise_high=%u disturber=%u "
			       "energy=%u distance_km=%d distance_code=%u valid=%u overhead=%u "
			       "out_of_range=%u indoor=%u powered_down=%u noise_floor=%u "
			       "watchdog=%u spike_rejection=%u minimum_lightnings=%u "
			       "mask_disturbers=%u tuning_cap=%u trco=0x%02x srco=0x%02x\n",
			       sample.interrupt_reason, sample.lightning, sample.noise_high,
			       sample.disturber, sample.energy, sample.distance_km,
			       sample.distance_code, sample.distance_valid, sample.storm_overhead,
			       sample.out_of_range, sample.indoor, sample.powered_down,
			       sample.noise_floor, sample.watchdog_threshold, sample.spike_rejection,
			       sample.minimum_lightnings, sample.disturbers_masked,
			       sample.tuning_capacitor, sample.trco_calibration, sample.srco_calibration);
		} else {
			printk("ERROR: AS3935 read: %d\n", err);
		}
	}
#endif
#if defined(CONFIG_APP_BLE) || defined(CONFIG_APP_SD_LOG)
#if defined(CONFIG_APP_BLE)
	telemetry_ble_publish(&frame);
#endif
#if defined(CONFIG_APP_SD_LOG)
	sd_log_submit(&frame);
#endif
#endif
}

static void monitor_sensors(void)
{
	opt_ready = report_init("OPT4001", init_errors[0] = opt4001_init());
	bme_ready = report_init("BME690", init_errors[1] = bme690_init());
	sgp_ready = report_init("SGP41", init_errors[2] = sgp41_init());
	stcc_ready = report_init("STCC4", init_errors[3] = stcc4_init());
#if defined(CONFIG_APP_BMV080)
	bmv_ready = report_init("BMV080", init_errors[4] = bmv080_driver_init());
#endif
#if defined(CONFIG_APP_SFA40)
	hcho_ready = report_init("SFA40", init_errors[6] = sfa40_init());
#endif
#if defined(CONFIG_APP_AS3935)
	lightning_ready = report_init("AS3935", init_errors[5] = as3935_init());
#endif
	/* STCC4 needs its first full continuous-measurement interval. */
	k_msleep(1100);
	int64_t first_ms = k_uptime_get();
	int64_t next_ms = first_ms;

	for (unsigned int sequence = 1; ; sequence++) {
		k_sleep(K_TIMEOUT_ABS_MS(next_ms));
		printk("SAMPLE %u at %lld ms\n", sequence,
		       (long long)(k_uptime_get() - first_ms));
		read_sensors(sequence);
		next_ms += 1000;
		int64_t now = k_uptime_get();

		if (next_ms <= now) {
			/* Skip expired slots instead of issuing measurements back-to-back. */
			int64_t missed = (now - next_ms) / 1000 + 1;

			next_ms += missed * 1000;
			printk("SAMPLE OVERRUN: skipped %lld interval(s)\n", (long long)missed);
		}
	}
}
#endif

#if defined(CONFIG_APP_BUZZER_TEST)
static int test_buzzer(void)
{
	printk("Buzzer timing: on %u ms, interval %u ms, count %u, startup %u ms\n",
	       CONFIG_BUZZER_ON_MS, CONFIG_BUZZER_INTERVAL_MS, CONFIG_BUZZER_BEEP_COUNT,
	       CONFIG_BUZZER_STARTUP_DELAY_MS);
	k_msleep(CONFIG_BUZZER_STARTUP_DELAY_MS);

	int64_t first_beep_ms = k_uptime_get();

	for (unsigned int i = 0; i < CONFIG_BUZZER_BEEP_COUNT; i++) {
		k_sleep(K_TIMEOUT_ABS_MS(first_beep_ms + (int64_t)i * CONFIG_BUZZER_INTERVAL_MS));
		int err = buzzer_start();
		if (err != 0) {
			printk("ERROR: cannot start buzzer: %d\n", err);
			return err;
		}
		printk("BUZZER ON %u/%u at %lld ms\n", i + 1, CONFIG_BUZZER_BEEP_COUNT,
		       (long long)(k_uptime_get() - first_beep_ms));
		k_msleep(CONFIG_BUZZER_ON_MS);

		err = buzzer_stop();
		if (err != 0) {
			printk("ERROR: cannot silence buzzer: %d\n", err);
			return err;
		}
		printk("BUZZER OFF %u/%u\n", i + 1, CONFIG_BUZZER_BEEP_COUNT);
	}
	printk("BUZZER DONE\n");
	return 0;
}
#endif

int main(void)
{
	int err = buzzer_init();

	if (err == 0) {
		err = buzzer_stop();
	}
	if (err != 0) {
		printk("ERROR: cannot silence buzzer: %d\n", err);
		return 0;
	}
	printk("BUZZER STOPPED\n");

#if defined(CONFIG_APP_BLE)
	err = telemetry_ble_init();
	if (err != 0) { printk("ERROR: BLE init: %d\n", err); }
#endif
#if defined(CONFIG_APP_I2C_SCAN)
	(void)scan_i2c();
#endif
#if defined(CONFIG_APP_BUZZER_TEST)
	(void)test_buzzer();
#endif
#if defined(CONFIG_APP_SENSOR_READ)
	monitor_sensors();
#endif
	return 0;
}

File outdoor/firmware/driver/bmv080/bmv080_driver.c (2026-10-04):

#include <bmv080_driver.h>

#include <errno.h>
#include <stddef.h>

#if defined(CONFIG_APP_BMV080)
#include <bmv080.h>
#include <math.h>
#include <zephyr/drivers/i2c.h>
#include <zephyr/kernel.h>
#include <zephyr/sys/byteorder.h>
#include <zephyr/sys/printk.h>

static const struct i2c_dt_spec bus = I2C_DT_SPEC_GET(DT_NODELABEL(bmv080));
static bmv080_handle_t handle;
static bool initialized;
static int last_bus_error;
static int current_error;
static int64_t received_ms;
static uint32_t last_read_sequence;
static struct bmv080_sample latest;
static uint8_t transfer_buffer[4098];
static struct k_thread worker;
K_THREAD_STACK_DEFINE(worker_stack, 16384);
K_MUTEX_DEFINE(sample_mutex);

static int8_t read_words(bmv080_sercom_handle_t context, uint16_t header,
			uint16_t *payload, uint16_t count)
{
	(void)context;
	if (payload == NULL || count == 0) {
		last_bus_error = -EINVAL;
		return -1;
	}
	/* I2C addresses are word addresses. A read requires STOP after the header. */
	sys_put_be16((uint16_t)(header << 1), transfer_buffer);
	last_bus_error = i2c_write_dt(&bus, transfer_buffer, 2);
	for (uint32_t offset = 0; last_bus_error == 0 && offset < count; ) {
		uint16_t words = MIN((uint32_t)count - offset, 128U);

		/* The BMV080 permits subsequent reads without another header. */
		last_bus_error = i2c_read_dt(&bus, transfer_buffer, words * 2);
		if (last_bus_error == 0) {
			for (uint16_t i = 0; i < words; i++) {
				payload[offset + i] = sys_get_be16(&transfer_buffer[i * 2]);
			}
			offset += words;
		}
	}
	return last_bus_error == 0 ? 0 : -1;
}

static int8_t write_words(bmv080_sercom_handle_t context, uint16_t header,
			 const uint16_t *payload, uint16_t count)
{
	(void)context;
	if ((payload == NULL && count != 0) || count > 2048) {
		last_bus_error = -EMSGSIZE;
		return -1;
	}
	sys_put_be16((uint16_t)(header << 1), transfer_buffer);
	for (uint16_t i = 0; i < count; i++) {
		sys_put_be16(payload[i], &transfer_buffer[2 + i * 2]);
	}
	last_bus_error = i2c_write_dt(&bus, transfer_buffer, 2 + count * 2);
	return last_bus_error == 0 ? 0 : -1;
}

static int8_t delay_ms(uint32_t duration)
{
	k_msleep(duration);
	return 0;
}

static int sdk_error(bmv080_status_code_t status)
{
	if (status == E_BMV080_OK) {
		return 0;
	}
	printk("ERROR: BMV080 SDK status=%d I2C=%d\n", (int)status, last_bus_error);
	return last_bus_error != 0 ? last_bus_error : -EIO;
}

static bool to_milli(float value, int32_t *result)
{
	if (!isfinite(value) || value < 0 || value > 2147483.0f) {
		return false;
	}
	*result = (int32_t)(value * 1000.0f);
	return true;
}

static void data_ready(bmv080_output_t output, void *context)
{
	(void)context;
	struct bmv080_sample sample = {
		.is_obstructed = output.is_obstructed,
		.is_outside_measurement_range = output.is_outside_measurement_range,
	};
	double runtime_ms = (double)output.runtime_in_sec * 1000.0;
	bool valid = isfinite(output.runtime_in_sec) && output.runtime_in_sec >= 0 &&
		     runtime_ms < 18446744073709551616.0 &&
		     to_milli(output.pm1_mass_concentration, &sample.pm1_mass_milliug_m3) &&
		     to_milli(output.pm2_5_mass_concentration, &sample.pm2_5_mass_milliug_m3) &&
		     to_milli(output.pm10_mass_concentration, &sample.pm10_mass_milliug_m3) &&
		     to_milli(output.pm1_number_concentration, &sample.pm1_number_milliparticles_cm3) &&
		     to_milli(output.pm2_5_number_concentration, &sample.pm2_5_number_milliparticles_cm3) &&
		     to_milli(output.pm10_number_concentration, &sample.pm10_number_milliparticles_cm3);

	k_mutex_lock(&sample_mutex, K_FOREVER);
	if (valid) {
		sample.runtime_ms = (uint64_t)runtime_ms;
		sample.sequence = latest.sequence + 1;
		latest = sample;
		received_ms = k_uptime_get();
		current_error = 0;
	} else {
		current_error = -EBADMSG;
	}
	k_mutex_unlock(&sample_mutex);
}

static void poll_sensor(void *unused1, void *unused2, void *unused3)
{
	(void)unused1;
	(void)unused2;
	(void)unused3;
	int previous_status = 0;

	for (;;) {
		last_bus_error = 0;
		bmv080_status_code_t status = bmv080_serve_interrupt(handle, data_ready, NULL);

		if (status != E_BMV080_OK) {
			k_mutex_lock(&sample_mutex, K_FOREVER);
			current_error = last_bus_error != 0 ? last_bus_error : -EIO;
			k_mutex_unlock(&sample_mutex);
			if ((int)status != previous_status) {
				(void)sdk_error(status);
			}
		}
		previous_status = status;
		k_msleep(status == E_BMV080_OK ? 10 : 100);
	}
}

int bmv080_driver_init(void)
{
	if (initialized) {
		return -EALREADY;
	}
	if (!i2c_is_ready_dt(&bus)) {
		return -ENODEV;
	}
	/* Leave enough transfer-time margin for the SDK's burst writes. */
	int err = i2c_configure(bus.bus, I2C_MODE_CONTROLLER | I2C_SPEED_SET(I2C_SPEED_FAST));

	if (err != 0) {
		return err;
	}
	err = sdk_error(bmv080_open(&handle, (void *)&bus, read_words, write_words, delay_ms));

	if (err != 0) {
		return err;
	}
	err = sdk_error(bmv080_reset(handle));
	char sensor_id[13] = {0};

	if (err == 0) {
		err = sdk_error(bmv080_get_sensor_id(handle, sensor_id));
	}
	if (err == 0) {
		printk("BMV080: sensor_id=%s\n", sensor_id);
		err = sdk_error(bmv080_start_continuous_measurement(handle));
	}
	if (err != 0) {
		(void)bmv080_close(&handle);
		return err;
	}
	initialized = true;
	k_thread_create(&worker, worker_stack, K_THREAD_STACK_SIZEOF(worker_stack),
			poll_sensor, NULL, NULL, NULL, K_PRIO_PREEMPT(5), 0, K_NO_WAIT);
	return 0;
}

int bmv080_driver_read(struct bmv080_sample *sample)
{
	if (sample == NULL) {
		return -EINVAL;
	}
	if (!initialized) {
		return -EACCES;
	}
	k_mutex_lock(&sample_mutex, K_FOREVER);
	int err = current_error;

	if (err == 0 && latest.sequence == 0) {
		err = -EAGAIN;
	}
	if (err == 0) {
		*sample = latest;
		sample->age_ms = (uint32_t)(k_uptime_get() - received_ms);
		sample->fresh = sample->sequence != last_read_sequence;
		last_read_sequence = sample->sequence;
	}
	k_mutex_unlock(&sample_mutex);
	return err;
}

#else

int bmv080_driver_init(void)
{
	return -ENOSYS;
}

int bmv080_driver_read(struct bmv080_sample *sample)
{
	return sample == NULL ? -EINVAL : -ENOSYS;
}

#endif

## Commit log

2026-10-04 Add outdoor env sensor firmware and software
    [BLE_TypeB1.STEP, BLE_TypeC1.STEP, BLE_TypeD1.STEP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]
2026-11-03 Add card sensor firmware, iOS app, enclosure, and shared drivers
